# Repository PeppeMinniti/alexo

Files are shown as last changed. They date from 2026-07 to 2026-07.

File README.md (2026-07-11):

# Alexo — assistente vocale fai-da-te su ESP32-S3

Alexo è un assistente vocale "tipo Alexa/Google Home" **costruito da zero** su un
microcontrollore **ESP32-S3**: ascolta una domanda a voce e risponde a voce, con tanto
di chat sul display e animazioni luminose. Tutto il progetto (codice, commenti,
interfaccia) è in **italiano**.

<p align="center">
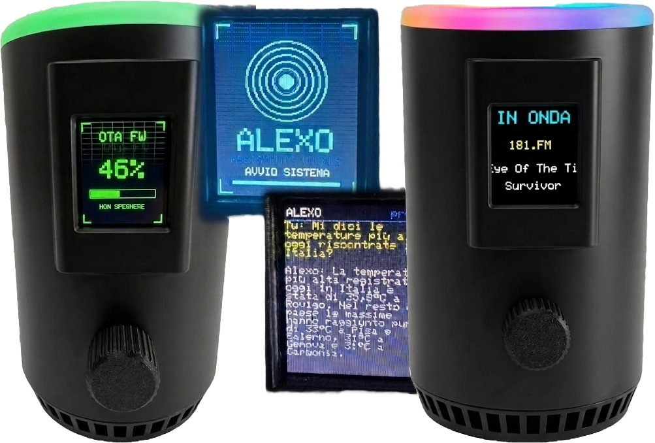
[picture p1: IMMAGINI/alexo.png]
Alexo — case stampato, splash di avvio, schermata OTA, chat sul display e schermata radio 'In onda'
  
</p>

> ⚠️ **Progetto hobbistico/educativo.** Per funzionare servono **3 API key tue**
> (vedi sotto). Nessuna garanzia: usalo a tuo rischio.

> 🖨️ **Il case è stampabile in 3D** — file `.3mf`/STL su
> **[MakerWorld](https://makerworld.com/it/models/3040023-alexo-ai-voice-assistant-case-esp32-s3)**
> (licenza CC BY 4.0).

---

## Come funziona

Alexo da solo è troppo piccolo per "ragionare": fa il **fattorino** tra alcuni servizi
cloud. L'unica intelligenza che gira in locale (offline) è il riconoscimento della parola
di attivazione.

```mermaid
flowchart TD
    START(["🗣️ Wake word 'Okay Nabu' (locale, offline)<br/>oppure click sull'encoder"])
    MIC["🎤 Microfono I2S<br/>registra la voce · stop automatico al silenzio"]
    STT["📤 Groq · Whisper<br/>voce → testo (STT, gratis)"]
    LLM["🧠 Claude · Anthropic<br/>il cervello · ricerca web"]
    TTS["🔊 ElevenLabs<br/>testo → voce (TTS, MP3)"]
    OUT["🔈 VS1053 → amplificatore → altoparlante"]
    UI["📺 Display TFT (chat) &nbsp;·&nbsp; 💍 Ring LED (stato)"]

    START --> MIC --> STT -->|testo| LLM -->|risposta| TTS --> OUT
    MIC -. aggiorna .-> UI
    LLM -. aggiorna .-> UI

    classDef cloud fill:#0e2a33,stroke:#00e5ff,color:#dfeef2;
    classDef ui fill:#1a1030,stroke:#ff2ea6,color:#dfeef2;
    class STT,LLM,TTS cloud;
    class UI ui;
```

Sul display TFT scorre la conversazione come un teleprompter; l'anello di LED cambia
animazione in base allo stato (ascolto / pensa / parla).

## Funzionalità

- 🗣️ **Wake word locale** "Okay Nabu" (microWakeWord / TensorFlow Lite Micro, offline)
- 🎛️ **Encoder** come comando unico (click per parlare, giro per scorrere/volume)
- 🧠 **Memoria della conversazione** + **ricerca web** (via Claude)
- ⏱️ **Stop automatico al silenzio** adattivo al rumore di fondo
- 📻 **Web-radio** MP3 ("metti radio…", cambio stazione dall'encoder)
- 🌐 **Pannello web** (`http://alexo.local/`): taratura parametri, volume, voci,
  personalità di Claude, e **chat in tempo reale** — senza ricompilare
- 🕒 **Ora reale** via NTP passata al cervello
- ⬆️ **Aggiornamento OTA** (via WiFi) oltre che via USB

## Hardware

| Componente | Modello | Ruolo |
| --- | --- | --- |
| MCU | ESP32-S3 **N16R8** (16 MB flash, 8 MB PSRAM) | il "computer" |
| Microfono | **ICS-43434** (I2S) | l'orecchio |
| Decoder audio | **VS1053 / VS1003** (SPI) | riproduce MP3 (voce e radio) |
| Amplificatore | **PAM8302A** | pilota l'altoparlante |
| Display | **ST7735** TFT 1.8" a colori | chat / teleprompter |
| Anello LED | **WS2812** 12 LED (NeoPixel) | animazioni di stato |
| Comando | Encoder rotativo **KY-040** | click / giro |

Schema dei collegamenti pin-per-pin e note di montaggio nel
[**MANUALE.md**](MANUALE.md) e in [CABLAGGIO_HW.md](CABLAGGIO_HW.md).

## Software

Firmware in **C++ / PlatformIO** (Arduino), modulare: `mic`, `net`, `stt`, `llm`, `tts`,
`music`, `ui` (LED), `gobbo` (display), `encoder`, `volume`, `sound`, `wakeword`,
`settings` + `webui` (pannello web). La pipeline pesante gira su un core, le animazioni
sull'altro, così restano fluide anche mentre Alexo "pensa".

## Come si costruisce (in breve)

1. **Clona** il repo e aprilo con [PlatformIO](https://platformio.org/) (in VS Code).
2. **Crea le tue chiavi API** (necessarie):
   - **Groq** (Whisper STT) — gratis su console.groq.com
   - **Anthropic** (Claude) — console.anthropic.com
   - **ElevenLabs** (voce TTS) — elevenlabs.io
3. **Configura i segreti**: copia `include/secrets.example.h` in `include/secrets.h` e
   inserisci WiFi + le 3 chiavi. (`secrets.h` è ignorato da git: non finirà nel repo.)
4. **Compila e carica** (primo flash via USB):
   
   ```
   pio run -e esp32-s3-devkitc-1 -t upload
   ```
   
   Serve caricare **una volta** anche la pagina del pannello web (cartella `data/`) nel
   filesystem dell'ESP — da ripetere solo se in futuro modifichi quella pagina:
     
   ```
   pio run -e esp32-s3-devkitc-1 -t uploadfs
   ```
 
5. Tutti i **pin e i parametri** stanno in [`include/config.h`](include/config.h) —
   unica fonte di verità.

La guida completa e spiegata passo-passo (con il *perché* di ogni scelta) è nel
[**MANUALE.md**](MANUALE.md). Dettagli sulla wake word in [WAKEWORD.md](WAKEWORD.md).

## Documentazione

- 📖 [MANUALE.md](MANUALE.md) — guida completa (hardware + software, spiegata semplice)
- 🔌 [CABLAGGIO_HW.md](CABLAGGIO_HW.md) — collegamenti pin-per-pin
- 🧩 [WAKEWORD.md](WAKEWORD.md) — la wake word locale nel dettaglio
- 🖨️ [Case 3D su MakerWorld](https://makerworld.com/it/models/3040023-alexo-ai-voice-assistant-case-esp32-s3) — file stampabili (`.3mf`/STL), licenza CC BY 4.0

---

## 👤 Autore

**Peppe Minniti** — *Automation Engineer* dal profilo atipico: nessun titolo in
ingegneria, tanta pratica. Costruisco sistemi che integrano hardware, software e
meccanica. Alexo è uno dei miei progetti. Il mio motto: **"Soluzioni che funzionano".**

### 🆘 Sei bloccato su un tuo ESP32?

**Lo risolviamo insieme, in diretta.** Diagnosi gratuita, poi sessione 1:1 in
condivisione schermo. → **[Vai a ESP32 SOS ›](https://www.peppeminniti.it/assistenza_esp32/)**

<sub>Oppure impara a costruirli tu: [corso completo "Dall'idea al sistema con ESP32"](https://www.peppeminniti.it/) · [Portfolio](https://www.peppeminniti.it/portfolio/) · [GitHub](https://github.com/PeppeMinniti) · [LinkedIn](https://www.linkedin.com/in/giuseppe-minniti-m2m-fablab)</sub>

## Licenza

Rilasciato sotto licenza **MIT** — vedi [LICENSE](LICENSE). Puoi usarlo, modificarlo e
ridistribuirlo liberamente, mantenendo la nota di copyright.

## Ringraziamenti

Ideazione, progettazione, scelte tecniche, prove sul campo e cura del risultato finale
sono di **Giuseppe Minniti**. Parte dello sviluppo è stata portata avanti in
collaborazione con un assistente AI (Claude, di Anthropic), usato come compagno di
lavoro: per confrontare idee, scrivere e commentare codice, rifinire la documentazione.

Mi piace pensarla come una collaborazione in cui si cresce a vicenda: l'AI non
sostituisce il lavoro e le decisioni umane, le affianca e le accelera. La direzione, il
senso critico e la responsabilità delle scelte restano di chi progetta — e proprio da
questo dialogo nasce l'occasione di imparare, per entrambe le parti.

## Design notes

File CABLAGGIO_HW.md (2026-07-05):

# ALEXO — Guida al cablaggio hardware

Riepilogo completo di **tutti** i collegamenti pin-a-pin tra i componenti, con
condensatori, resistenze, varianti di nomenclatura serigrafata sui moduli e
buone norme. Niente schemi ASCII: solo elenchi "da pin a pin".

Fonte dei pin: [`include/config.h`](include/config.h) — **unica fonte di verità**.
Se cambi un cablaggio, modifica i `#define` lì, non altrove.

---

## Premesse generali (valgono per tutto)

- **L'ESP32-S3 lavora a 3.3V sui pin.** Mai mettere 5V su un GPIO. I moduli si
  alimentano dal pin `5V` (chiamato anche `VIN` / `VBUS`) o dal `3V3` della
  board a seconda del componente — specificato sotto per ognuno.
- **GND comune obbligatorio.** Tutti i GND di tutti i moduli (mic, VS1053,
  display, ring, encoder, bottone) devono finire sullo stesso GND della ESP32.
  Senza massa comune i segnali "ballano" e niente funziona. È la regola d'oro:
  se un modulo si comporta in modo strano, il primo sospetto è sempre una massa
  mancante o ballerina.
- **Pin da NON toccare** su questa board (ESP32-S3 N16R8): GPIO 33–37 (PSRAM
  octal), 19/20 (USB), 0/3/45/46 (strapping). Sono già evitati nella config.

---

## Microfono — DUE opzioni (se ne collega UNA sola)

La scelta si fa con `MIC_USE_I2S` in [`config.h`](include/config.h):
`1` = mic I2S digitale ICS-43434 (**in uso ora**), `0` = MAX4466 analogico
(backend alternativo). L'API software è identica → cambi solo la riga, ricompili,
ricabli.

### Opzione A — MAX4466 analogico (alternativo, `MIC_USE_I2S 0`)

| Pin sul modulo MAX4466 | Va collegato a | Note |
|---|---|---|
| `VCC` (`VDD` / `V` / `+`) | **3V3** della ESP32 | **Non** 5V: a 5V il livello DC di riposo esce dal range dell'ADC |
| `GND` (`G` / `-`) | GND comune | — |
| `OUT` (`AUD` / `A0` / `S`) | **GPIO4** (ADC1_CH3) | uscita analogica |

**Condensatore (importante, già previsto nel progetto):** **470 µF elettrolitico
tra VCC e GND del MAX4466**, il più vicino possibile al modulo. Disaccoppia
l'alimentazione: senza, i NeoPixel che si accendono "sporcano" la tensione e il
mic capta i loro disturbi (l'idle reattivo non funziona). Polarità: gamba lunga
(+) su VCC, gamba corta / lato con striscia chiara e segno `–` su GND.

Il guadagno si regola col **trimmer sul retro** del MAX4466 (cacciavite piccolo),
nessuna resistenza esterna.

### Opzione B — mic I2S digitale ICS-43434 / INMP441 (IN USO ORA, `MIC_USE_I2S 1`)

Microfono digitale: niente ADC, niente condensatori di disaccoppiamento (sparisce
del tutto l'accoppiamento LED→mic). Alimentare a **3V3**.

| Pin sul modulo I2S | Va collegato a | Nomi possibili sul modulo |
|---|---|---|
| Alimentazione | **3V3** | `VDD`, `VCC`, `3V3`, `+` |
| Massa | GND comune | `GND`, `G`, `-` |
| Bit clock | **GPIO5** | `SCK`, `BCLK`, `CLK`, `SCLK` |
| Word select | **GPIO6** | `WS`, `LRCL`, `LRCLK`, `FS` |
| Dati dal microfono | **GPIO7** | `SD`, `DOUT`, `DATA`, `DO` |
| Selezione canale | **GND** | `L/R`, `SEL`, `LRSEL` → a **GND = canale LEFT** (quello che il codice si aspetta) |

> Sul modulo INMP441 può esserci anche `VDD`/`GND` doppi: collega comunque tutti
> i GND. Il pin `L/R` a GND seleziona LEFT; a 3V3 selezionerebbe RIGHT (da evitare).

**Buone norme I2S:**
- Niente resistenze/condensatori esterni necessari.
- Dopo lo swap va **ri-tarata** la soglia dell'idle reattivo
  (`MIC_LVL_NOISE` / `MIC_LVL_GAIN` nel ramo I2S di [`src/mic.cpp`](src/mic.cpp))
  e l'`I2S_SHIFT` in config (alza = più volume, conversione 32→16 bit).
- I tre fili dati (SCK/WS/SD) tienili cortini e lontani dai fili audio/SPI.

---

## VS1053 (decoder MP3 → altoparlante, bus SPI)

È il modulo con più nomi diversi sulla serigrafia. Per ogni funzione elenco
**tutte** le diciture possibili (LC Technology, Adafruit, Sparkfun, cloni):

| Funzione / pin nel codice | GPIO ESP32 | Nomi possibili sul modulo |
|---|---|---|
| **Alimentazione** | `5V` | `5V`, `VCC`, `V+`, `VIN` — i moduli LC Technology vogliono **5V** (regolatore a bordo) |
| **Massa** | GND | `GND`, `G`, `-` |
| **Clock SPI (SCK)** | `GPIO12` | `SCK`, `SCLK`, `CLK`, `C` |
| **Dati verso il VS1053 (MOSI)** | `GPIO11` | `MOSI`, `SI`, `DI`, `SDI`, `DIN` |
| **Dati dal VS1053 (MISO)** | `GPIO13` | `MISO`, `SO`, `DO`, `SDO`, `DOUT` |
| **Chip Select comandi (XCS)** | `GPIO10` | `XCS`, `CS`, `SCS`, `xCS` |
| **Chip Select dati (XDCS)** | `GPIO21` | `XDCS`, `DCS`, `BSYNC`, `SDCS`, `X-DCS` |
| **Data Request (DREQ)** | `GPIO18` | `DREQ`, `DREQ/INT`, `DQ`, `D-REQ` — **uscita** del VS1053 (input per la ESP32): "sono pronto a ricevere altri dati". Spostato da GPIO47 a **GPIO18** |
| **Reset (XRST)** | `GPIO8` | `XRST`, `RST`, `RESET`, `XRESET`, `RES` — spostato da GPIO38 (era il "BUILTIN LED" della board: sporcava XRST durante il float di boot → reset del VS1003 inaffidabile a freddo) |

Altri pin presenti sul connettore VS1053 e cosa farne:
- **`AGND` / `LOUT` / `ROUT` / `GBUF`**: uscita audio analogica / cuffie.
  `LOUT`/`ROUT` = canale sinistro/destro, `GBUF` = massa virtuale cuffie.
  Vanno all'altoparlante (via ampli o jack), **non** alla ESP32.
- **Slot microSD** (`CARD_CS` o un secondo gruppo `CS/SCK/MISO/MOSI`): molti
  moduli LC Technology ce l'hanno sullo stesso bus SPI. Se non lo usi, lascialo
  scollegato (CS della SD non collegato = SD disabilitata).
- **`MIDI` / `RX` / `GPIO0..3` del VS1053**: pin di modalità/MIDI, non servono.

**Buone norme VS1053:**
- È sullo **stesso bus SPI (FSPI)** della board (SCK/MOSI/MISO condivisi); il
  display sta su un **bus separato (HSPI)** apposta per non litigare. Non
  spostare il VS1053 sul bus del display.
- Se "si pianta" sui suoni brevi (bip) è un comportamento noto del chip già
  gestito nel codice (niente `stopSong`, si manda una coda di silenzio). Non è
  un problema di cablaggio.

> ⚠️ Conflitto da ricordare: `GPIO13` è MISO del VS1053 **e** sarebbe `I2S_SHIFT`
> nel ramo I2S — ma sono mutuamente esclusivi (il `13` lì è solo un parametro
> numerico di shift, non un pin). Nessun conflitto reale.

---

## Amplificatore PAM8302A (ampli Class-D mono → altoparlante)

Amplifica l'uscita di linea del VS1053 per pilotare un altoparlante a volume
pieno. L'**ingresso** del PAM si prende dall'uscita audio del VS1053, **non** da
un GPIO.

| Funzione / pin nel codice | Va collegato a | Nomi possibili sul modulo |
|---|---|---|
| **Alimentazione** | `5V` | `VDD`, `VCC`, `V+`, `5V` (regge 2.0–5.5V) |
| **Massa** | GND comune | `GND`, `G`, `-` |
| **Ingresso audio +** | **`LOUT`** (o `ROUT`) del VS1053 | `IN+`, `A+`, `IN`, `L` |
| **Ingresso audio −** | **`AGND`** del VS1053 | `IN-`, `A-`, `GND audio` |
| **Shutdown** | **`GPIO39`** | `SD`, `/SD`, `SHDN`, `EN` |
| **Uscita +/−** | altoparlante | `+`/`-`, `OUT+`/`OUT-` |

**Pin SD (shutdown), ATTIVO BASSO — gestito dal firmware:**
- `HIGH` = ampli acceso; `LOW` = ampli **muto** (consumo ~0, **niente fruscio**
  Class-D di fondo, niente pop). Sulla maggior parte delle breakout, se lasci SD
  **scollegato** l'ampli resta acceso (pull-up a bordo).
- Il firmware lo tiene acceso **solo durante l'interazione** (bip + voce) e muto
  a riposo: vedi `AMP_SD_PIN` in [`config.h`](include/config.h) e `ampEnable()`
  in [`src/main.cpp`](src/main.cpp). Metti `AMP_SD_PIN -1` per disabilitare il
  controllo (ampli sempre acceso).
- **Per provarlo "fisso acceso"**: porta SD alla **stessa tensione di VDD**
  (se alimenti il PAM a 5V → SD a 5V). Mai SD sopra la VDD dell'ampli.

> Nota pin: `GPIO39` fa parte del gruppo JTAG (MTCK), già rinunciato dal progetto
> (40/41/42 = MTDO/MTDI/MTMS sono il display). Nessun conflitto.

---

## Encoder rotativo KY-040 (scroll della chat sul display)

| Funzione / pin nel codice | GPIO ESP32 | Nomi possibili sul modulo |
|---|---|---|
| **Alimentazione** | **3V3** | `+`, `VCC`, `V`, `5V` (sul KY-040 c'è scritto `+`; **alimentalo a 3V3**, non 5V) |
| **Massa** | GND | `GND`, `G`, `-` |
| **Canale A (CLK)** | `GPIO15` | `CLK`, `A`, `OUT_A`, `S1`, `ENC_A` |
| **Canale B (DT)** | `GPIO16` | `DT`, `B`, `OUT_B`, `S2`, `ENC_B` |
| **Pulsante (premere la manopola)** | `GPIO17` | `SW`, `KEY`, `BTN`, `PUSH`, `S` |

> ⚠️ **Cablaggio fisico vs firmware (situazione attuale, funzionante):** sopra c'è
> il cablaggio FISICO reale (CLK→GPIO15, DT→GPIO16). In [`config.h`](include/config.h)
> però i `#define` sono **invertiti apposta** — `ENC_A_PIN 16`, `ENC_B_PIN 15` —
> per correggere via software il verso di rotazione (A/B erano risultati scambiati
> in saldatura). **Non "raddrizzare" i define per farli combaciare con questa
> tabella**: girando i due valori si inverte il senso dello scroll. Così com'è,
> gira e scrolla nel verso giusto.

Funzione: girare = scorri la chat su/giù; premere il pulsante = torna "live".

**Resistenze / condensatori sull'encoder:**
- Il **KY-040** ha già a bordo due resistenze di pull-up (10kΩ) su CLK e DT. Con
  un encoder "nudo" servirebbero pull-up esterne — ma in pratica si usano le
  **pull-up interne della ESP32** via software (`INPUT_PULLUP`): non saldi nulla.
- Gli encoder meccanici "rimbalzano". Opzionale: **100 nF ceramico tra CLK e GND
  e un altro tra DT e GND** pulisce molto la lettura. I ceramici **non** hanno
  polarità, vanno in qualunque verso.

---

## Bottone push-to-talk — RIMOSSO (l'encoder è l'unico comando)

Non c'è un bottone dedicato: il contenitore ha il **solo encoder**. Il pulsante
dell'encoder fa tutto. **GPIO14**, ex push-to-talk, è ora riusato per il
**backlight del display** (vedi sezione TFT ST7735).

Gesti dell'encoder (vedi [`src/gobbo.cpp`](src/gobbo.cpp)):

| Gesto | Effetto |
|---|---|
| **Click** (a riposo) | avvia la chat (inizia a registrare) |
| **Click** (mentre registra) | ferma e invia *(toggle)* |
| **Premuto + giro** | volume su/giù |
| **Giro libero** | scroll della chat |

> Predisposizione per il futuro vocale: il "click di avvio" sarà rimpiazzato dal
> **wake-word** e il "click di stop" dal **rilevamento del silenzio**, senza
> toccare il resto della pipeline (start/stop sono già eventi separati).

---

## Ring NeoPixel WS2812 (12 LED)

| Pin sul ring | Va collegato a | Note |
|---|---|---|
| `5V` (`VCC` / `+5V` / `PWR` / `+`) | **5V** | i WS2812 vogliono 5V per colori pieni |
| `GND` (`-` / `G`) | GND comune | — |
| `DIN` (`DI` / `IN` / `Data In`, segui la freccia ➜ stampata) | **GPIO48** | il dato entra dal lato `DIN`, non `DOUT` |

**Condensatori e resistenze (raccomandati, in parte già nel progetto):**
- **1000 µF elettrolitico tra 5V e GND del ring**, vicino al ring. Già previsto:
  assorbe i picchi di corrente quando i LED cambiano colore insieme (altrimenti
  disturbano il mic). Polarità: + su 5V, – (striscia chiara) su GND.
- **Resistenza ~330 Ω in serie sul filo DIN** (tra GPIO48 e l'ingresso dati del
  ring). Protegge il primo LED e fa da rimedio anti-EMI. Senza polarità; va *in
  linea* sul filo dati (taglia il filo e metti la resistenza in mezzo).

**Nota EMI (già documentata):** tieni il filo `DIN` del ring **lontano** dai fili
SCLK/MOSI del display, altrimenti l'accoppiamento elettromagnetico fa lampeggiare
il ring durante lo scroll. La resistenza serie da 330 Ω sul DIN aiuta anche qui.

---

## Display TFT ST7735 1.8" (bus SPI dedicato HSPI)

| Funzione / pin nel codice | GPIO ESP32 | Nomi possibili sul modulo |
|---|---|---|
| Clock | `GPIO2` | `SCK`, `SCL`, `CLK` |
| Dati | `GPIO1` | `SDA`, `MOSI`, `DIN`, `SI` |
| Chip Select | `GPIO42` | `CS`, `LCD_CS` |
| Data/Command | `GPIO41` | `DC`, `A0`, `RS`, `D/C` |
| Reset | `GPIO40` | `RES`, `RST`, `RESET` |
| Alimentazione | `3V3` | `VCC`, `VDD` |
| Massa | GND | `GND` |
| Retroilluminazione | `GPIO14` | `LED`, `BL`, `BLK` |

**Retroilluminazione su GPIO (novità):** il pin `LED`/`BL` **non** va più a 3V3
fisso ma a **GPIO14** (era libero, ex push-to-talk). Così il firmware può
**spegnere il display a riposo** (dopo `DISPLAY_SLEEP_MS`, default 2 min) e
riaccenderlo al primo intervento. Il pin assorbe **~2 mA** (misurati): si pilota
**direttamente dal GPIO**, *niente transistor né resistenza esterna* (il catodo
del LED è già a GND dentro il modulo, e la resistenza di limitazione è a bordo).
HIGH = acceso, LOW = spento. Se volessi tenerlo sempre acceso: `DISPLAY_SLEEP_MS 0`
in [`config.h`](include/config.h).

Nessun passivo extra oltre a quelli a bordo del modulo. Se vedi "garbage" a
schermo è questione di clock SPI (scendi da 24 MHz a 16/20 MHz in config), non di
cablaggio.

---

## Riepilogo componenti passivi da avere

| Componente | Quantità | Dove | Polarità? |
|---|---|---|---|
| Elettrolitico **470 µF** | 1 | VCC↔GND del MAX4466 (solo mic analogico) | **Sì** (+ su VCC) |
| Elettrolitico **1000 µF** | 1 | 5V↔GND del ring | **Sì** (+ su 5V) |
| Resistenza **330 Ω** | 1 | in serie sul filo DIN del ring | No |
| Ceramico **100 nF** | 0–2 (opz.) | CLK↔GND e DT↔GND dell'encoder | No |

> Con il **mic I2S** il 470 µF del mic **non serve più** (mic digitale).

**Polarità di un elettrolitico, in due parole:** gamba **lunga = +**; sul corpo
c'è una **striscia chiara col segno `–`** dal lato della gamba corta. Il `+` va
verso l'alimentazione (VCC o 5V), il `–` verso GND. Resistenze e ceramici si
montano in qualunque verso.

---

## Tabella riassuntiva GPIO usati

> 📌 Pinout di riferimento in [`IMMAGINI/`](IMMAGINI/): `esp32-S3-DevKitC-1.png`
> (vista dall'alto, lato componenti) e `esp32-S3-DevKitC-1_LATO-SALDATURE.png`
> (vista da **sotto**, lato saldature — lati invertiti ma testo leggibile, utile
> mentre saldi guardando il retro della board).

| GPIO | Componente | Segnale |
|---|---|---|
| 1 | TFT ST7735 | MOSI/SDA |
| 2 | TFT ST7735 | SCLK/SCL |
| 4 | MAX4466 | OUT (ADC1) — *solo mic analogico* |
| 5 | mic I2S | BCLK — *solo mic I2S* |
| 6 | mic I2S | WS — *solo mic I2S* |
| 7 | mic I2S | SD (dati) — *solo mic I2S* |
| 10 | VS1053 | XCS |
| 11 | VS1053 | MOSI |
| 12 | VS1053 | SCK |
| 13 | VS1053 | MISO |
| 14 | TFT ST7735 | LED/BL (backlight, ex push-to-talk) |
| 15 | Encoder | A / CLK |
| 16 | Encoder | B / DT |
| 17 | Encoder | SW (pulsante = avvia/ferma chat) |
| 21 | VS1053 | XDCS |
| 8 | VS1053 | XRST (spostato da GPIO38 = builtin LED) |
| 39 | PAM8302A | SD (shutdown ampli) |
| 40 | TFT ST7735 | RST |
| 41 | TFT ST7735 | DC/A0/RS (Data/Command) |
| 42 | TFT ST7735 | CS |
| 18 | VS1053 | DREQ (spostato da GPIO47) |
| 48 | Ring WS2812 | DIN |

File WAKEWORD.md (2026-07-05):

# ALEXO — Wake word locale (microWakeWord)

Wake word **offline** sull'ESP32-S3 per avviare la chat a voce, in parallelo al
click encoder. Tutto in locale (nessun cloud per il wake).

> Stato: ✅ **FUNZIONANTE** — wake word **"Okay Nabu"** integrato e testato.
> Tutti i passi sotto sono FATTI. Implementazione in
> `src/wakeword.cpp` (+ `src/wake_model.h`, `lib/microfrontend/`), attiva con
> `WAKE_ENABLE 1` in `config.h`.
>
> **Parola attuale = "Okay Nabu"** (modello pre-addestrato): si pronuncia
> bene ed è preciso. Scartati "hey jarvis" (non colto per l'accento) e "alexa"
> (scattava su qualsiasi "-xa"). **"Alexo" CUSTOM** = unico upgrade rimasto (serve
> allenare un modello microWakeWord via Colab; nessuna registrazione, voci
> sintetiche; ~30-60 min con guida). Drop-in: sostituire `wake_model.h` + i `WAKE_*`.
>
> **Tuning finale**: WAKE_GAIN=4, WAKE_PROB_CUTOFF=240, WAKE_WINDOW=5. Lezioni:
> il modello è STREAMING → vuole flusso CONTINUO (niente delay tra le letture, o
> non rileva); troppo guadagno SATURA e peggiora; dopo l'interazione servono
> `micFlush()`+`wakeReset()` o riparte da solo sull'audio stantio.

## Architettura target

```
🎤 I2S 16kHz (continuo) → [feature frontend: 40 mel ogni 10ms]
   → modello microWakeWord INT8 (MixNet streaming, inferenza ogni 20ms, <10ms su S3)
   → probabilità wake → soglia + debounce (N inferenze consecutive sopra soglia)
   → TRIGGER: stesso ingresso del click encoder (gobboTakeTalkRequest)
              → pipeline cloud già pronta (Groq → Claude → ElevenLabs)
```

Il wake **sostituisce solo l'avvio**; tutto il resto della pipeline è invariato.
Il click encoder resta come avvio manuale e come stop.

## Dati tecnici (verificati giu 2026)

- Modello: **INT8 TFLite ~200–240 KB**, architettura MixNet streaming (stato interno).
- Frontend: **40 feature spettrali ogni 10 ms** (tipo mel/micro_speech, con
  noise-suppression + AGC nel preprocessore).
- Inferenza ogni **20 ms** sull'ultima stride; **<10 ms** su ESP32-S3 (con esp-nn).
- RAM: **~350 KB** (tensor arena) → allocare in **PSRAM** (`ps_malloc`), ne abbiamo 8 MB.
- Flash: il modello (~240 KB) come array `const` in `.rodata` (16 MB di flash, ampio).

## Toolchain TFLite Micro — LA decisione critica (da validare con un build)

Il progetto è Arduino/PlatformIO; TFLite Micro nasce ESP-IDF. Due strade:

1. **`esp-tflite-micro`** (Espressif): massima performance (kernel ottimizzati
   `esp-nn` sulle istruzioni vettoriali dell'S3). È un componente ESP-IDF: in
   PlatformIO-Arduino va aggiunto come componente, integrazione più delicata.
2. **Libreria Arduino che impacchetta TFLM + microfrontend** (es. EdgeNeuron, o un
   port `tflite-micro` per Arduino): più facile da mettere in `lib_deps`, ma può
   non avere l'accelerazione esp-nn e usare una versione TF più vecchia.

> **Azione**: provare a buildare un'inferenza MINIMALE con (1) e, se troppo
> ostico in Arduino, ripiegare su (2). Questo è il primo vero esperimento: finché
> non compila e gira una `Invoke()` su un tensore fittizio, il resto è teoria.

## Passi (in ordine, ciascuno verificabile via OTA)

1. **[FATTO] Step 0 — mic pulito.** Passa-alto + shift 15 + diagnostica `MIC_DIAG`.
2. **TFLite Micro compila e gira.** Aggiungere la lib scelta, far girare una
   `Invoke()` banale on-device (anche su input finto). Verifica: nessun crash,
   tempi di inferenza stampati su Telnet (`netlog`). ← de-risk della toolchain.
3. **Frontend feature.** Generare le 40 feature/10 ms dallo stream I2S (libreria
   microfrontend di TFLM). Verifica: dump dei valori su Telnet con voce vs silenzio.
4. **Modello PRE-ADDESTRATO.** Scaricare un modello pronto da
   `esphome/micro-wake-word-models` (es. "hey jarvis"), incorporarlo come array,
   collegarlo frontend→modello, stampare la probabilità su Telnet. Verifica:
   pronunciando la parola la probabilità sale. ← prova che la catena funziona.
5. **Soglia + debounce + trigger.** Sopra soglia per N inferenze consecutive →
   chiama l'avvio chat (stesso punto del click encoder). Tuning anti-falsi-positivi.
6. **Modello "Alexo" CUSTOM.** Allenarlo col Colab di `OHF-Voice/micro-wake-word`
   (campioni sintetici via TTS), esportare INT8, sostituire l'array del passo 4.
7. **Rifinitura**: gestione stato "sordo durante la chat", rientro in ascolto,
   eventuale doppia conferma, consumo.

## Stato implementazione (aggiornato giu 2026)

- **Passo 2 FATTO ✅**: TFLite Micro gira sull'S3. Lib = **Chirale_TensorFlowLite**
  (in `platformio.ini`). Self-test `hello_world` (`TFL_SELFTEST` + `src/tfltest.cpp`
  + `src/tfl_hello_model.h`): inferenza 38–132 µs, output corretti. `esp-tflite-micro`
  scartato (gira male in PlatformIO).
- **Modello scelto**: microWakeWord **v2 "alexa"** (vicino ad "Alexo"), da
  `esphome/micro-wake-word-models/models/v2/alexa.tflite`. Già incorporato in
  **`src/wake_model.h`** (`g_wake_model`, 55856 byte, INT8). Manifest v2:
  `probability_cutoff=0.9`, `sliding_window_size=5`, `feature_step_size=10ms`,
  `tensor_arena_size=22348` (~22 KB, in PSRAM). Detection: media mobile della
  probabilità su 5 step > 0.9 (+ refrattario anti-ripetizione).

### Frontend feature — specifica ESATTA (deve combaciare col training)
Preprocessore micro_speech / **TFLM microfrontend** (`tensorflow/lite/experimental/
microfrontend/lib/`), config da `preprocessor_settings.h` di ESPHome:
- sample rate **16000**, finestra **30 ms** (480 camp.), passo **10 ms** (160 camp.)
- **40** canali mel, banda **125–7500 Hz**
- noise reduction: smoothing_bits=10, even=0.025, odd=0.06, min_signal_remaining=0.05
- PCAN: enable=true, strength=0.95, offset=80.0, gain_bits=21
- log scale: enable=true, scale_shift=6
- output: 40 feature INT8/UINT8 per slice (un'inferenza ogni step da 10 ms).

### Vendorizzazione microfrontend (passo 3, IN CORSO)
Chirale NON include il microfrontend → va vendorizzato in `lib/microfrontend/`.
File core da `tensorflow/lite/experimental/microfrontend/lib/` (no _io/_test/_main/
memmap/BUILD): frontend, frontend_util, filterbank(+util), noise_reduction(+util),
pcan_gain_control(+util), log_scale(+util), log_lut, window(+util), fft, fft_util,
kiss_fft_int16, kiss_fft_common.h, bits.h. **Dipendenza kissfft**: kiss_fft_int16
include, dentro `namespace kissfft_fixed16` con `FIXED_POINT=16`, i sorgenti kissfft
`kiss_fft.h/.c`, `tools/kiss_fftr.h/.c` (+ `_kiss_fft_guts.h`) dal repo
mborgerding/kissfft alla versione di `tensorflow/lite/micro/tools/make/kissfft_download.sh`
(+ `third_party/kissfft/kissfft.patch`). Struttura lib PlatformIO:
`lib/microfrontend/src/tensorflow/...` (per gli include assoluti TFLM) e i sorgenti
kissfft raggiungibili come `kiss_fft.h`/`tools/kiss_fftr.h` dall'include path.

## Integrazione audio (nota importante)

Oggi a riposo il `loop()` fa `micPeekLevel()` (un `i2s_read` per il ring reattivo).
Col wake servirà leggere **tutto** lo stream in continuo: si unificherà la lettura
I2S a riposo in modo che lo **stesso** chunk alimenti sia il livello del ring sia
il buffer del wake (niente doppio `i2s_read`, altrimenti il modello perde metà
audio). Vedi seam in `wakeword.cpp` / `main.cpp` (`WAKE_ENABLE`).

## Cosa serve da te (in parallelo)

- Per il passo 6: far girare il **Colab di microWakeWord** per allenare "Alexo"
  (genera campioni sintetici, ~decine di minuti). Output: un `.tflite` INT8 + i
  parametri del frontend. Te lo guido quando arriviamo lì.
- Per i passi 2–5 non serve nulla da te se non flashare e leggere il Telnet.

## Fonti
- microWakeWord: https://microwakeword.com/ (train: https://microwakeword.com/train)
- Repo training: https://github.com/OHF-Voice/micro-wake-word
- Modelli pronti: https://github.com/esphome/micro-wake-word-models
- esp-tflite-micro: https://github.com/espressif/esp-tflite-micro
- ESPHome micro_wake_word: https://esphome.io/components/micro_wake_word/
- Guida pratica S3+TFLM: https://dev.to/zediot/esp32-s3-tensorflow-lite-micro-a-practical-guide-to-local-wake-word-edge-ai-inference-5540

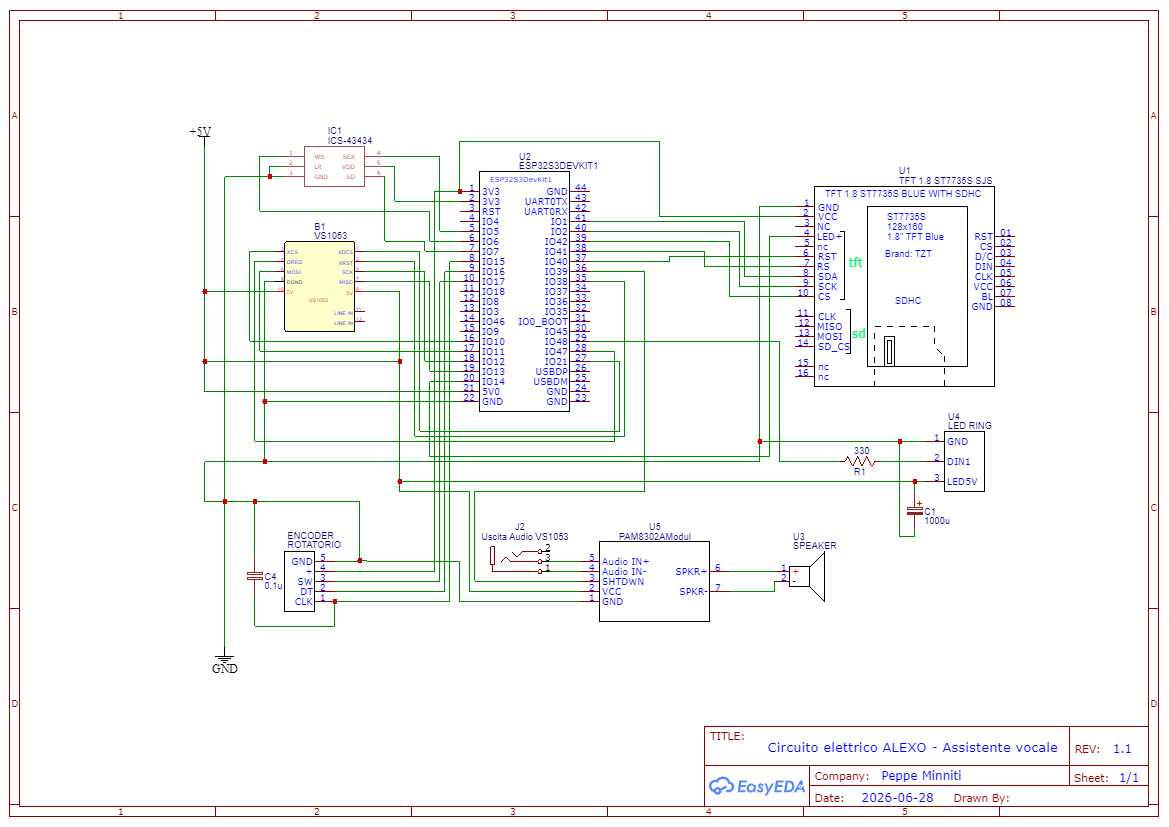
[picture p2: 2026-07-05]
IMMAGINI/Schematic_alexo_2026-07-04.png

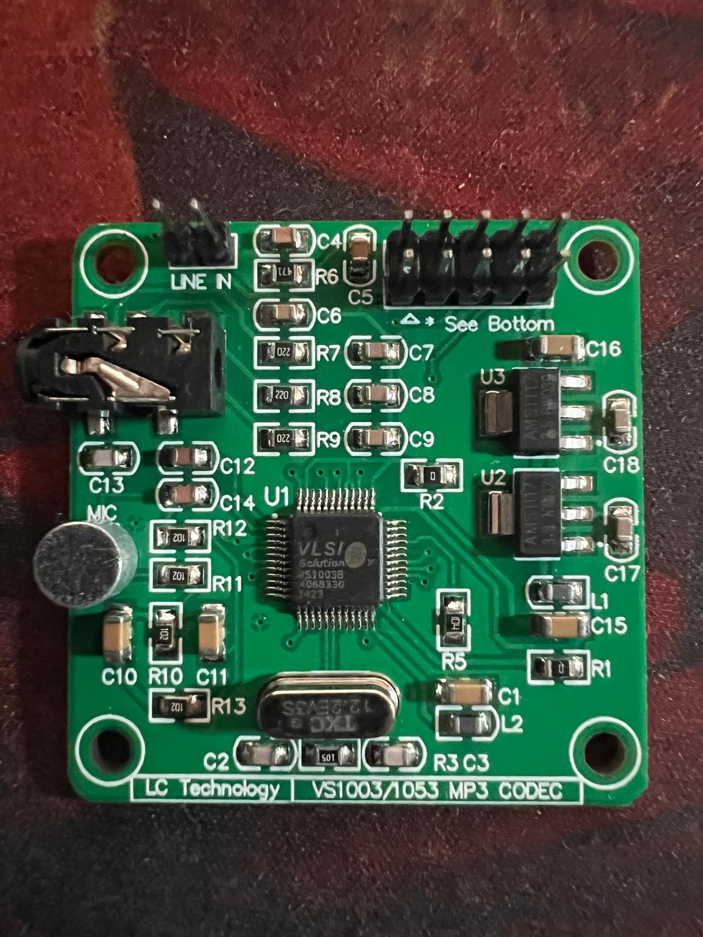
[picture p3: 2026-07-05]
IMMAGINI/codec_mp3.jpeg

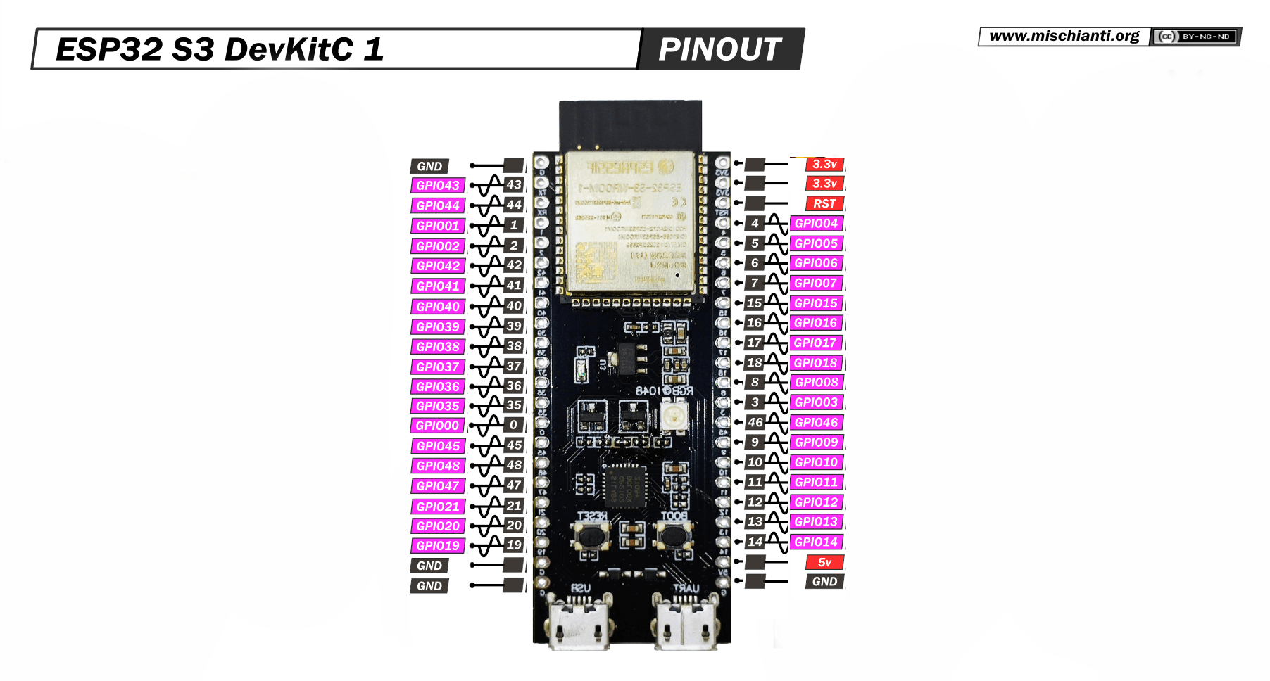
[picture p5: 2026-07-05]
IMMAGINI/esp32-S3-DevKitC-1_LATO-SALDATURE.png

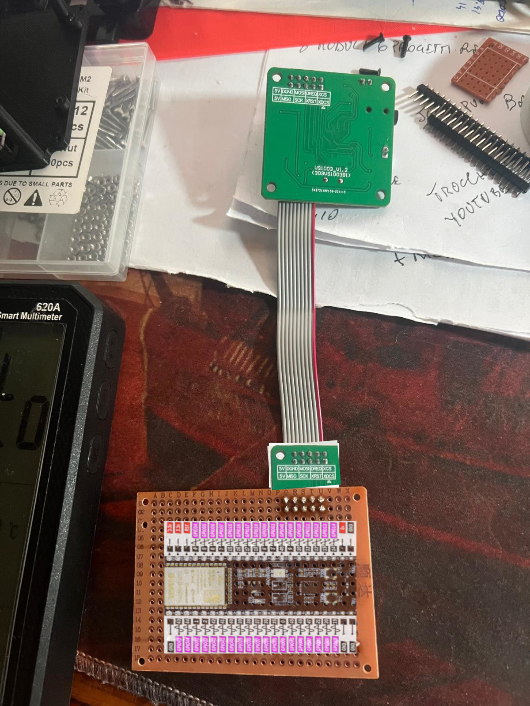
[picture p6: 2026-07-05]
IMMAGINI/basette.jpeg

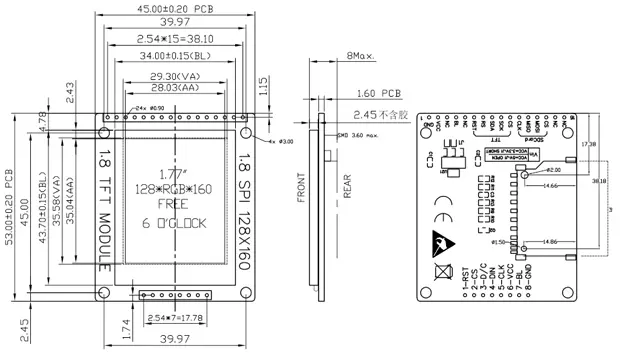
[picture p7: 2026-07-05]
IMMAGINI/Drawing1.8-inch-TFT-1.webp

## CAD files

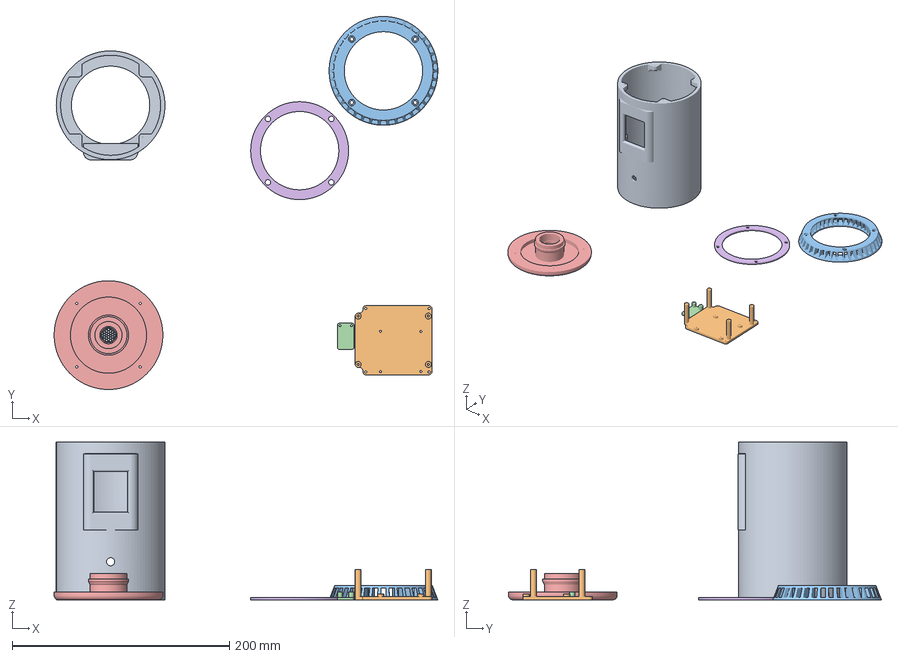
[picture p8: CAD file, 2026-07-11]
3d/Alexo.3mf
352.8 x 343.0 x 145.0 mm
contenitore.stl
basetta vs1053-1.stl
base.stl
basetta ampli.stl
coperchio portaled.stl
guarnizione.stl

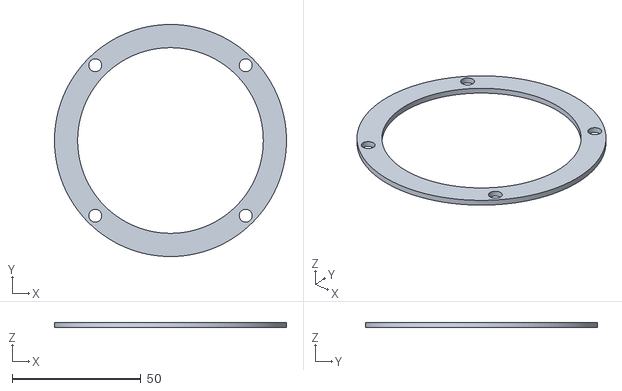
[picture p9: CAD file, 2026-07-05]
3d/guarnizione.stl
90.0 x 90.0 x 2.00

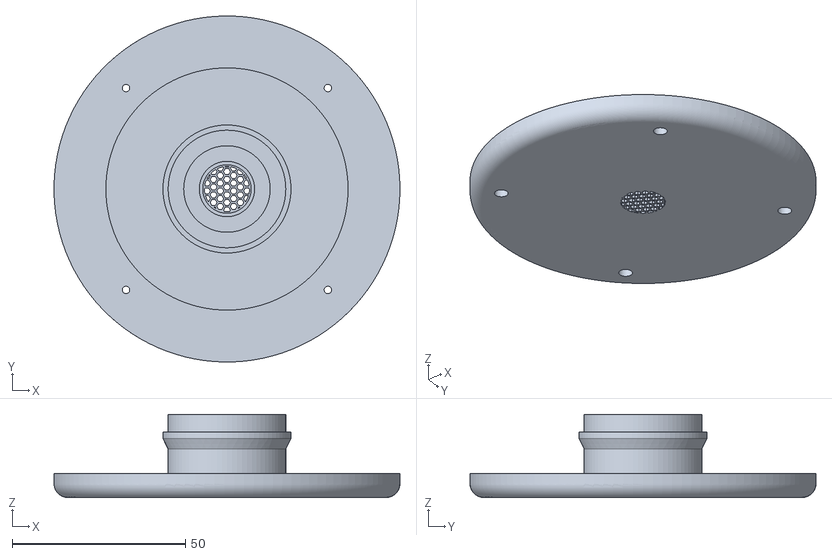
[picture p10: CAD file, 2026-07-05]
3d/coperchio portaled.stl
100.0 x 100.0 x 24.0

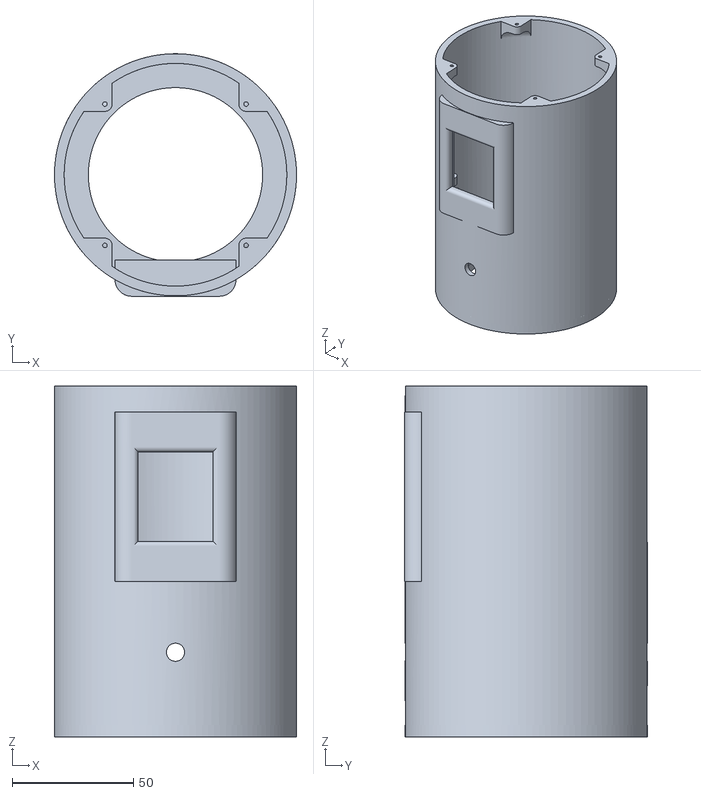
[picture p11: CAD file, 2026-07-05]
3d/contenitore.stl
100.0 x 100.2 x 145.0

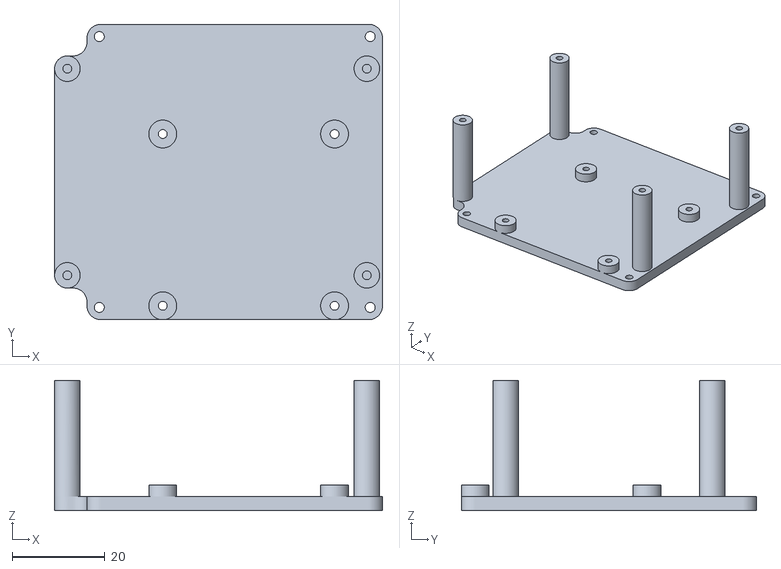
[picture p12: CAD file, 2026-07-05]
3d/basetta vs1053.stl
70.6 x 63.6 x 28.0

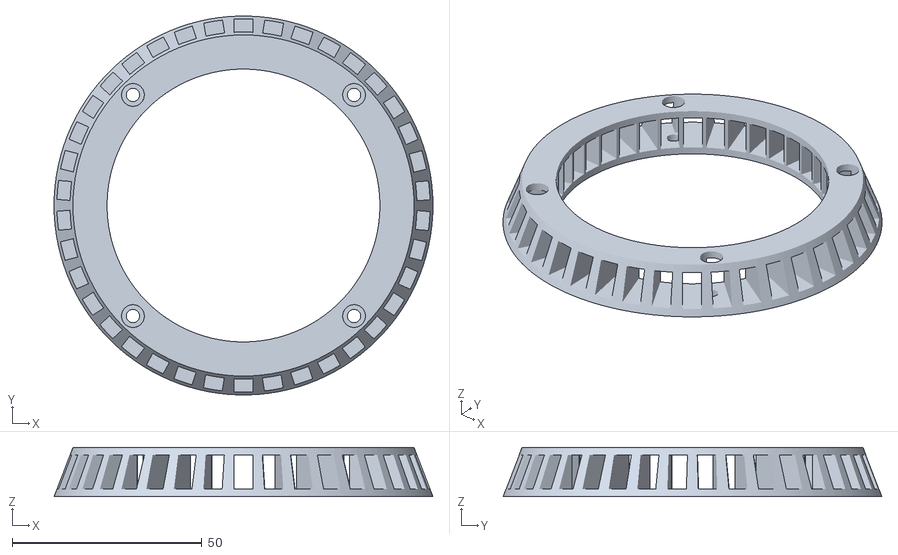
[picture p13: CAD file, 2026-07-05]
3d/base.stl
100.0 x 100.0 x 13.0

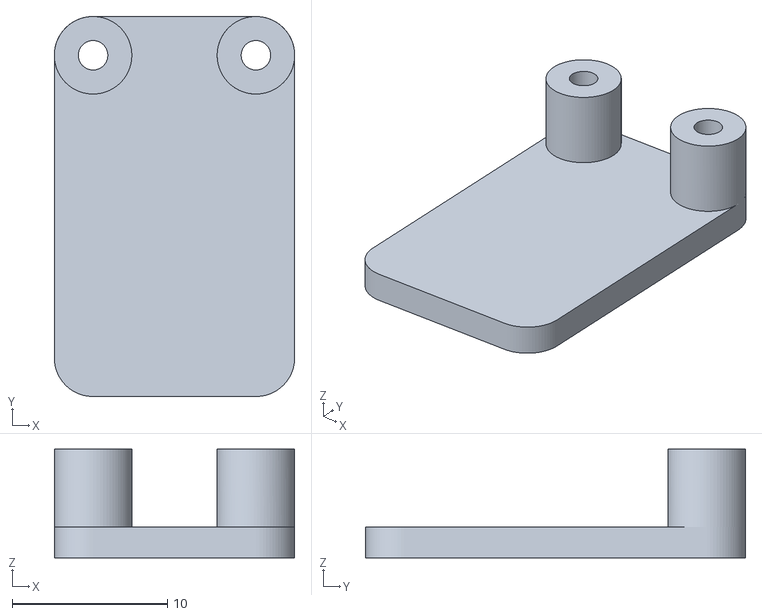
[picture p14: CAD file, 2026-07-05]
3d/basetta ampli.stl
15.5 x 24.5 x 7.00

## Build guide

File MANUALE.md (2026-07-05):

# MANUALE DI REALIZZAZIONE — ALEXO

**Assistente vocale "tipo Alexa" fai-da-te su ESP32-S3.**

Questo manuale spiega **come è fatto Alexo**, sia dal lato dei **collegamenti
elettrici** (cosa si salda a cosa e perché) sia dal lato del **programma** (cosa
fa ogni pezzo di codice). È scritto per essere capito anche senza essere esperti:
ogni concetto difficile è spiegato con parole semplici e con un esempio.

> Questo manuale racconta anche il *perché* delle scelte, non solo il *come*: così,
> se qualcosa nel tuo montaggio è diverso, capisci dove mettere le mani.

---

## Indice

1. [Cos'è Alexo e come "ragiona"](#1-cosè-alexo-e-come-ragiona)
2. [La catena vocale spiegata semplice](#2-la-catena-vocale-spiegata-semplice)
3. [I componenti (la spesa) e a cosa servono](#3-i-componenti-la-spesa-e-a-cosa-servono)
4. [I collegamenti elettrici, pezzo per pezzo](#4-i-collegamenti-elettrici-pezzo-per-pezzo)
5. [Alimentazione e le "trappole" hardware da conoscere](#5-alimentazione-e-le-trappole-hardware-da-conoscere)
6. [Il software: come è organizzato](#6-il-software-come-è-organizzato)
7. [Le impostazioni fondamentali (config.h e secrets.h)](#7-le-impostazioni-fondamentali)
8. [Come funziona il programma, modulo per modulo](#8-come-funziona-il-programma-modulo-per-modulo)
9. [La "macchina a stati": il ciclo di vita di una domanda](#9-la-macchina-a-stati)
10. [La wake word "Okay Nabu" spiegata semplice](#10-la-wake-word-okay-nabu-spiegata-semplice)
11. [Compilare e caricare il firmware](#11-compilare-e-caricare-il-firmware)
12. [Diagnostica e risoluzione problemi](#12-diagnostica-e-risoluzione-problemi)
13. [Come personalizzare Alexo](#13-come-personalizzare-alexo)
14. [Il pannello impostazioni web](#14-il-pannello-impostazioni-web)
15. [La musica: ascoltare la web-radio](#15-la-musica-ascoltare-la-web-radio)

---

## 1. Cos'è Alexo e come "ragiona"

Alexo è un piccolo dispositivo che **ascolta una domanda a voce e risponde a
voce**, come Alexa o Google Home. La differenza è che ce lo siamo costruiti noi,
su un microcontrollore **ESP32-S3**.

Il "cervello" vero e proprio (l'intelligenza artificiale che capisce e risponde)
**non gira dentro Alexo**: gira nel cloud. Alexo da solo è troppo piccolo per
farlo. Quindi Alexo fa il **fattorino**: registra la tua voce, la manda su
Internet a dei servizi specializzati, riceve la risposta e la fa parlare.

**Analogia:** immagina un centralinista. Non sa lui la risposta, ma sa a chi
telefonare per averla, e poi te la riferisce. Alexo è quel centralinista.

L'unica cosa "intelligente" che Alexo fa **da solo, offline**, è accorgersi
quando dici la parola magica ("Okay Nabu") per svegliarsi. Quello sì, lo fa in
casa, senza Internet.

---

## 2. La catena vocale spiegata semplice

Quando fai una domanda, l'informazione passa attraverso una **catena** di
passaggi. Ogni freccia è una "telefonata" via Internet (HTTPS):

```mermaid
flowchart TD
    START(["🗣️ Dici 'Okay Nabu' → Alexo si sveglia (in locale, offline)<br/>in alternativa: click sull'encoder"])
    MIC["🎤 Il microfono registra la tua voce<br/>(finché non fai ~1,5 s di silenzio)"]
    STT["📤 GROQ · Whisper<br/>l'audio diventa TESTO"]
    LLM["🧠 CLAUDE · Anthropic<br/>legge il testo e scrive la RISPOSTA<br/>(può cercare sul web)"]
    TTS["🔊 ELEVENLABS<br/>la risposta-testo diventa VOCE (MP3)"]
    OUT["🔈 L'audio esce dall'altoparlante"]
    DISP["📺 Sul display scorre la conversazione"]

    START --> MIC --> STT -->|testo| LLM -->|risposta| TTS --> OUT
    LLM -. nel frattempo .-> DISP

    classDef cloud fill:#0e2a33,stroke:#00e5ff,color:#dfeef2;
    classDef ui fill:#1a1030,stroke:#ff2ea6,color:#dfeef2;
    class STT,LLM,TTS cloud;
    class DISP ui;
```

Perché tre servizi diversi e non uno solo?

- **Groq/Whisper** è bravissimo a trasformare **voce → testo** (si chiama STT,
  *Speech To Text*). Ed è gratis.
- **Claude** è il cervello: legge il testo e scrive la risposta. È bravo a
  *capire e ragionare*, ma lavora solo col testo, non con l'audio.
- **ElevenLabs** è bravissimo a trasformare **testo → voce** (si chiama TTS,
  *Text To Speech*), con una voce naturale (addirittura clonata dalla voce
  dell'utente).

Ognuno fa il mestiere che sa fare meglio. Alexo li mette in fila.

> **Servono 3 chiavi (API key)**: una per Groq, una per Anthropic (Claude), una
> per ElevenLabs. Sono come password personali per usare quei servizi. Si
> ottengono gratis/registrandosi sui rispettivi siti. Dove si mettono lo vediamo
> nel [capitolo 7](#7-le-impostazioni-fondamentali).

---

## 3. I componenti (la spesa) e a cosa servono

| Pezzo | Modello | A cosa serve (in parole semplici) |
| --- | --- | --- |
| **Cervello elettronico** | ESP32-S3 **N16R8** | Il microcontrollore. È il "computer" che coordina tutto. Ha WiFi integrato, 16 MB di memoria flash (dove sta il programma) e 8 MB di PSRAM (memoria di lavoro, dove tiene l'audio registrato). |
| **Microfono** | **ICS-43434** (I2S) | L'orecchio. È un microfono *digitale*: manda già i numeri, non un segnale analogico da interpretare → più pulito. |
| **Decoder audio** | **VS1003/VS1053** (SPI) | La "scheda audio". Riceve un flusso MP3 (la voce di ElevenLabs, oppure una **web-radio**) e lo trasforma in suono vero. L'ESP32 da solo non saprebbe suonare un MP3. ⚠️ Decodifica **solo MP3** (niente AAC): conta per le radio, vedi [cap. 15](#15-la-musica-ascoltare-la-web-radio). |
| **Amplificatore** | **PAM8302A** | Alza il volume del segnale del VS1053 abbastanza da far suonare l'altoparlante. Da solo il decoder è troppo debole. |
| **Altoparlante** | uno qualsiasi piccolo | La bocca. Emette il suono. |
| **Display** | **ST7735** TFT 1.8" a colori | Lo schermo. Mostra la chat (le tue domande e le risposte) come un teleprompter che scorre. |
| **Anello LED** | **WS2812** 12 LED (NeoPixel) | Le "luci di stato". Cambiano animazione a seconda di cosa sta facendo Alexo (ascolta, pensa, parla). |
| **Manopola** | **Encoder rotativo** KY-040  | Il comando fisico. Si clicca per avviare/fermare, si gira per scorrere la chat o cambiare volume. |

> Nota storica: all'inizio si era provato un microfono analogico **MAX4466** e un
> pulsante separato. Il codice supporta ancora il MAX4466 (basta cambiare
> un'impostazione), ma la versione attuale usa il microfono digitale ICS-43434 e
> l'encoder come unico comando.

---

## 4. I collegamenti elettrici, pezzo per pezzo

> ⚠️ **Regola d'oro:** i numeri dei pin dell'ESP32 li decidiamo noi nel file
> [`include/config.h`](include/config.h). Quel file è l'**unica fonte di
> verità**: se ricabli qualcosa, cambi *solo* lì e tutto il resto del programma
> si adegua da solo. Le tabelle qui sotto rispecchiano i valori attuali di
> `config.h`.

Prima due concetti che tornano sempre:

- **GPIO** = "General Purpose Input/Output", cioè i piedini programmabili
  dell'ESP32. Ognuno ha un numero (es. GPIO14). Alcuni sono "speciali" e vanno
  evitati (lo spieghiamo sotto).
- **Bus SPI / I2S** = "autostrade" di comunicazione. Più dispositivi possono
  condividere la stessa autostrada, ma serve un pilota. Alexo usa **due bus SPI
  separati** apposta (uno per l'audio, uno per il display) così non si intralciano.

### 4.1 Microfono ICS-43434 (bus I2S)

Il microfono digitale parla la lingua **I2S** (tre fili di segnale + alimentazione).

| Pin del microfono | Va a… | Note |
| --- | --- | --- |
| VDD | **3V3** | alimentazione 3,3 V |
| GND | **GND** | massa |
| SCK (clock) | **GPIO5** | il "metronomo" |
| WS (word select)  | **GPIO6** | dice quando è il turno del canale sinistro/destro |
| SD (dati) | **GPIO7** | qui viaggiano i numeri dell'audio |
| L/R | **GND** | messo a massa = il mic usa il canale **sinistro** |

### 4.2 Decoder audio VS1053/VS1003 (bus SPI "audio", detto FSPI)

Questo è il pezzo più delicato da cablare. Condivide 3 fili (SCK, MOSI, MISO)
ma ha 4 fili di controllo tutti suoi.

| Pin del VS1053 | Va a… | A cosa serve |
| --- | --- | --- |
| SCK | **GPIO12** | clock del bus SPI |
| MOSI (SI) | **GPIO11** | dati che vanno *verso* il chip |
| MISO (SO) | **GPIO13** | dati che tornano *dal* chip |
| XCS | **GPIO10** | "chip select" per i **comandi** |
| XDCS | **GPIO21** | "chip select" per i **dati** (il flusso MP3) |
| DREQ | **GPIO18** | il chip dice "sono pronto, dammi altri dati" |
| XRST | **GPIO8** | reset hardware del chip |
| LOUT / ROUT / AGND | → ingresso amplificatore | l'audio analogico che esce |
| Alimentazione | **5V** e GND | |

> **Perché DREQ è su GPIO18 e XRST su GPIO8, e non altrove?** All'inizio erano
> su GPIO47 e GPIO38. Ma il **GPIO38** è collegato al LED di bordo della scheda:
> quel circuito "sporcava" il segnale di reset all'accensione e il chip audio a
> volte non si avviava (partenza "a freddo" inaffidabile). Spostandolo su GPIO8
> il problema è sparito. È un esempio di quanto la scelta dei pin conti.

### 4.3 Amplificatore PAM8302A

| Pin del PAM8302A | Va a… | Note |
| --- | --- | --- |
| A+ / A− (ingresso) | **LOUT/ROUT + AGND del VS1053** | prende il suono debole dal decoder  |
| VCC | **5V** | alimentazione |
| GND | **GND** | |
| SD (shutdown) | **GPIO39** | accende/spegne l'ampli (vedi sotto) |
| uscita + / − | **altoparlante** | |

> **Il trucco del pin SD (GPIO39).** L'amplificatore, quando è acceso e non c'è
> suono, fa un leggero "fruscio" fastidioso. Allora lo teniamo **spento a
> riposo** e lo **accendiamo solo un attimo prima di parlare**. Il pin SD è
> "attivo basso": mettere GPIO39 a livello ALTO = ampli acceso, a livello BASSO =
> ampli muto (consumo quasi zero, niente fruscio). Nel codice lo fa la funzione
> `ampEnable()`.

### 4.4 Display TFT ST7735 (bus SPI "display", detto HSPI — separato!)

| Pin del display | Va a… | Note |
| --- | --- | --- |
| SCLK (SCL) | **GPIO2**  | clock (bus separato dall'audio) |
| MOSI (SDA/DIN) | **GPIO1**  | dati verso il display |
| CS | **GPIO42** | chip select |
| DC (A0/RS) | **GPIO41** | "questo è un comando o un dato?" |
| RST (RES) | **GPIO40** | reset |
| LED/BL (retroilluminazione) | **GPIO14** | accende/spegne la luce dello schermo |
| VCC | **3V3** | |
| GND | **GND** | |

> **Due dettagli furbi sul display:**
> 
> 1. **Bus separato (HSPI):** il display sta su un'autostrada tutta sua, diversa
>    da quella dell'audio. Così, mentre la chat scorre sullo schermo (gestita da
>    un "core" del processore), l'audio non fa singhiozzi (gestito dall'altro
>    core). Sono due lavoratori che non si pestano i piedi.
> 2. **Retroilluminazione su GPIO14:** invece di tenere la luce sempre accesa,
>    la pilotiamo noi. Dopo 2 minuti di inattività Alexo la **spegne** per
>    risparmiare, e la riaccende al primo comando. Il pin assorbe pochissimo
>    (~2 mA), quindi lo colleghiamo direttamente senza transistor.

### 4.5 Anello LED WS2812 (NeoPixel)

| Pin del ring | Va a… |
| --- | --- |
| DIN (dati) | **GPIO48** |
| 5V | **5V** |
| GND | **GND** |

> **Attenzione al filo dati (DIN):** i suoi impulsi elettrici possono
> "disturbare" i fili vicini. Va tenuto **lontano** dai fili del display (SCLK/
> MOSI). Se dà problemi (LED che lampeggiano a caso durante lo scroll), si può
> mettere una resistenza da ~330 Ω in serie sul DIN.

### 4.6 Encoder rotativo (la manopola)

| Pin dell'encoder | Va a… | Note |
| --- | --- | ---- |
| CLK (A) | **GPIO16** | |
| DT (B) | **GPIO15** | |
| SW (pulsante) | **GPIO17** | |
| + | **3V3** | |
| GND | **GND** | |

> Nota: se dopo il montaggio "orario" e "antiorario" risultano **invertiti** (capita
> facilmente scambiando i fili A e B), non è un problema: basta scambiare i due pin
> `CLK` e `DT` in `config.h`.

---

## 5. Alimentazione e le "trappole" hardware da conoscere

### 5.1 Come si alimenta

Il sistema si alimenta dai **5V** (ad esempio da un alimentatore USB). Il microfono
e il display vogliono **3,3 V**; il decoder audio, l'amplificatore e il ring vogliono
**5 V**. Entrambe le tensioni si prendono dalla scheda ESP32 (che ha sia il pin 3V3 sia
il 5V), con la **massa (GND) in comune** a tutto.

> Se alimenti dal pin **5V** della DevKitC-1, verifica sul tuo modello se quel pin è già
> collegato al rail interno o se serve chiudere un ponticello "IN-OUT" sulla scheda (su
> alcuni cloni dual-USB-C il 5V è isolato di default).

### 5.2 I condensatori di disaccoppiamento (importantissimi!)

**Problema scoperto sul campo:** quando i LED del ring si accendono, "succhiano"
corrente a strappi. Questi strappi, viaggiando sull'alimentazione, arrivavano
fino al microfono e lo **sporcavano** di rumore. Risultato: le luci reattive al
suono impazzivano e la registrazione era disturbata.

**Soluzione:** due **condensatori** fanno da "serbatoio d'acqua" che assorbe gli
strappi e tiene stabile la tensione:

- **470 µF** sul VCC del microfono
- **1000 µF** sul 5V del ring LED

> Analogia: è come mettere una cisterna vicino a un rubinetto che viene aperto e
> chiuso di continuo. La cisterna assorbe i colpi e a valle l'acqua resta stabile.

### 5.3 Altre due trappole risolte (utili da sapere)

1. **Il fading dei LED "a scatti".** Impostare la luminosità globale dei NeoPixel
   a un valore basso *quantizza* le sfumature (restano pochi livelli, il fading si
   vede a gradoni). Soluzione: tenere la luminosità globale al **massimo (255)** e
   usare valori bassi **direttamente** nei colori delle animazioni.
2. **Il primo "bip" e poi silenzio.** Il decoder VS1053, quando gli mandi il
   comando `stopSong()` su suoni molto brevi, si "incanta". Soluzione: non usare
   `stopSong()`; invece si mandano i dati del suono seguiti da un po' di
   **silenzio** (byte a zero) che spinge fuori l'ultimo pezzo. Lo stesso trucco
   vale per la voce e per i bip.

---

## 6. Il software: come è organizzato

Il programma è scritto in **C++** con l'ambiente **PlatformIO** (dentro VS Code).
È diviso in tanti file piccoli, ognuno con un compito. Questo si chiama
"modularità": è come una cucina dove ogni cuoco fa un piatto.

```
include/               ← le "etichette" (dichiarazioni) + le impostazioni
  config.h             ← ★ TUTTI i pin e i parametri. Si modifica QUI.
  secrets.example.h    ← modello per le password/chiavi (da copiare in secrets.h)
  *.h                  ← una "etichetta" per ogni modulo sotto

src/                   ← il codice vero e proprio
  main.cpp             ← il DIRETTORE D'ORCHESTRA: coordina tutto
  mic.cpp              ← registra dal microfono
  net.cpp              ← si connette al WiFi
  stt.cpp              ← manda l'audio a Groq → riceve il testo
  llm.cpp              ← manda il testo a Claude → riceve la risposta
  tts.cpp              ← manda la risposta a ElevenLabs → suona la voce
  music.cpp            ← riproduce la web-radio (flusso MP3 → VS1053)
  ui.cpp               ← anima l'anello LED
  gobbo.cpp            ← disegna la chat sul display
  encoder.cpp          ← legge la manopola
  volume.cpp           ← gestisce il volume (e lo ricorda)
  sound.cpp            ← genera i "bip" di conferma
  netlog.cpp           ← invia i log via rete (per leggerli senza cavo USB)
  settings.cpp         ← parametri modificabili "a caldo", salvati in memoria (NVS)
  webui.cpp            ← il web server del pannello impostazioni
  wakeword.cpp         ← riconosce "Okay Nabu" (l'unica IA locale)

data/                  ← file serviti dal web server (via LittleFS)
  index.html           ← la pagina del pannello impostazioni
```

**Due "core" (due cervelli nel processore).** L'ESP32-S3 ha due nuclei di
calcolo. Alexo li usa così:

- **Core 1**: fa la pipeline pesante (registrazione + telefonate a Internet).
- **Core 0**: fa le animazioni (LED, display, lettura encoder).

Perché? Perché le telefonate a Internet **bloccano** chi le fa per qualche
secondo. Se le animazioni fossero sullo stesso core, si congelerebbero. Tenendole
su un core separato, restano fluide anche mentre Alexo "pensa".

---

## 7. Le impostazioni fondamentali

### 7.1 `config.h` — i pin e i comportamenti

È il pannello di controllo. Alcuni esempi di cose che si regolano lì:

- I **numeri dei pin** di ogni componente (capitolo 4).
- `MIC_USE_I2S` → `1` usa il mic digitale, `0` il vecchio analogico.
- `IDLE_REACTIVE` → `1` fa "ballare" i LED col suono quando Alexo è a riposo.
- `REC_SILENCE_MS 1500` → dopo 1,5 s di silenzio la registrazione si chiude da sola.
- `REC_MAX_MS 20000` → non registra mai più di 20 secondi.
- `WAKE_ENABLE 1` → attiva la wake word "Okay Nabu".
- `DISPLAY_SLEEP_MS 120000` → spegne lo schermo dopo 2 minuti di inattività.
- Vari flag di **diagnostica** (`MIC_DIAG`, `WAKE_TEST`, `TFL_SELFTEST`) che
  vedremo nel capitolo 12.

### 7.2 `secrets.h` — le password (NON si condivide!)

Le credenziali WiFi e le 3 chiavi API stanno in un file a parte,
`include/secrets.h`, che **non viene mai messo online** (è escluso da git). Si
crea copiando il modello:

```
include/secrets.example.h   →   copia e rinomina in   →   include/secrets.h
```

E dentro si compilano i valori veri:

```cpp
#define WIFI_SSID        "il-nome-del-tuo-wifi"
#define WIFI_PASSWORD    "la-tua-password"
#define GROQ_API_KEY       "gsk_..."     // per Whisper (voce→testo), gratis
#define ANTHROPIC_API_KEY  "sk-ant-..."  // per Claude (il cervello)
#define ELEVENLABS_API_KEY "sk_..."      // per la voce (testo→voce)
```

> ⚠️ Le chiavi API sono come password: **mai** metterle in file pubblici o
> condividerle. Se una si "brucia", si rigenera dal sito del servizio.

### 7.3 La configurazione critica anti "boot loop"

C'è un dettaglio nel file `platformio.ini` che **non va toccato**. La scheda
N16R8 ha 16 MB di flash, ma il "profilo" standard la crede da 8 MB. Senza queste
righe il dispositivo entra in **boot loop** (si riavvia all'infinito):

```ini
board_upload.flash_size  = 16MB           ; dice la verità sulla dimensione
board_upload.maximum_size = 16777216
board_build.arduino.memory_type = qio_opi ; attiva gli 8 MB di PSRAM
```

Se un giorno vedi solo messaggi strani e continui riavvii sulla seriale, il
sospetto numero uno è questo.

---

## 8. Come funziona il programma, modulo per modulo

### `mic.cpp` — l'orecchio

Registra l'audio dal microfono a **16.000 campioni al secondo** (è la "risoluzione"
che vuole Whisper) e lo mette nella PSRAM (la memoria grande).

Cose intelligenti che fa:

- **Passa-alto ~120 Hz:** un filtro che toglie i rumori bassi (il "rimbombo" e
  la componente continua del microfono), lasciando passare la voce. È il
  segreto che ha reso la registrazione pulita.
- **Stop automatico al silenzio (adattivo):** mentre registri, misura l'energia
  media del suono; se sente 1,5 s di silenzio *dopo* che hai parlato, chiude da
  sola. Così non devi premere "stop". La soglia che distingue "voce" da "silenzio"
  **non è fissa**: si calcola sopra il rumore di fondo stimato in tempo reale
  (`soglia = fondo × margine + minimo`), così si adatta da sola se cambia il
  rumore ambientale (una stanza più o meno rumorosa). Usa la media (RMS) e non il
  picco, perché i rumori impulsivi (un colpo, una folata d'aria sul microfono) fanno
  picchi isolati altissimi che ingannerebbero il picco ma non la media. Questi due
  valori (`margine` e `minimo`) sono regolabili dal
  [pannello web](#14-il-pannello-impostazioni-web).
- **Livello per i LED:** dallo stesso audio calcola quanto "forte" stai parlando,
  per far reagire l'anello luminoso. Usa un "envelope follower" (un valore che
  sale piano e scende piano) per evitare che i LED sfarfallino sui rumori isolati.
- **"Ho sentito voce vera?"** Tiene traccia se durante la registrazione il suono ha
  davvero superato la soglia (`micHeardVoice`). Serve alla difesa anti-fantasma
  (vedi sotto).

#### Il filtro anti-fantasma di Whisper

Ogni tanto capita un **falso avvio** (la wake word che si ri-attiva sulla coda
audio, o un disturbo): parte una registrazione che contiene solo silenzio/rumore.
Il riconoscitore vocale (Whisper), messo davanti al silenzio, **"allucina"**: in
italiano quasi sempre inventa *"Grazie"*, *"Grazie a tutti"* o *"Sottotitoli a cura
di…"*. Il risultato era che Alexo faceva partire una risposta dal nulla.

Due difese (in `main.cpp`):

1. **Se non è stata sentita voce vera**, Alexo torna a riposo **senza nemmeno
   chiamare Whisper** (usa `micHeardVoice`). Taglia il problema alla radice.
2. **Filtro sulle frasi-fantasma:** se comunque la trascrizione è *esattamente* una
   frase-fantasma nota, la scarta in silenzio. La **lista è modificabile dal
   [pannello web](#14-il-pannello-impostazioni-web)**, così ne aggiungi di nuove
   senza ricompilare.

### `net.cpp` — il WiFi

Si collega alla rete di casa usando le credenziali di `secrets.h`. Serve una rete
a **2,4 GHz** (l'ESP32 non parla il 5 GHz).

Fa anche una cosa fondamentale per gli orari: **sincronizza l'orologio via NTP**
(un servizio Internet che dà l'ora esatta), impostando il fuso italiano con il
cambio ora legale automatico. Da qui `nowContextString()` produce la stringa
data/ora (locale + UTC) che finisce nel cervello (`llm.cpp`). Senza NTP, l'ESP32
partirebbe dal 1970 e Claude non saprebbe che ora è.

### `stt.cpp` — da voce a testo (STT)

Prende l'audio registrato (in formato WAV), lo impacchetta in una richiesta web
"multipart" (come allegare un file a un modulo) e lo invia a **Groq**. Groq usa
il modello **Whisper** e restituisce il testo di ciò che hai detto. Alexo estrae
il campo `text` dalla risposta.

### `llm.cpp` — il cervello (Claude)

Il pezzo più "intelligente". Invia il tuo testo all'API di **Anthropic** (modello
`claude-haiku-4-5`, veloce ed economico) e riceve la risposta. Punti chiave:

- **System prompt:** una "istruzione permanente" dice a Claude di essere Alexo,
  di rispondere breve e colloquiale (2-3 frasi, niente elenchi né emoji, perché
  poi va letto ad alta voce).
- **Memoria della conversazione:** conserva gli ultimi 8 messaggi, così puoi fare
  domande di seguito ("e a Milano?" dopo aver chiesto il meteo di Roma). Dopo 2
  minuti di inattività la memoria si azzera (nuova conversazione).
- **Ricerca web:** Claude può cercare su Internet da solo (meteo, notizie,
  prezzi) fino a 3 volte per domanda. Alexo poi legge solo il riassunto.
- **Data e ora reali:** a ogni domanda, Alexo aggiunge al system prompt la data e
  l'ora attuali (locale + UTC), prese dall'orologio sincronizzato via Internet
  (vedi `net.cpp`). Senza, Claude **non sa che ora è adesso** e sbaglierebbe sia
  "che ore sono" sia il calcolo dei fusi delle altre città (che ricava dall'UTC).

### `tts.cpp` — da testo a voce (TTS)

Manda la risposta a **ElevenLabs**, che restituisce un file **MP3** con la voce.
L'MP3 non arriva tutto insieme: arriva "a pezzetti" (streaming) e ogni pezzetto
viene subito passato al decoder VS1053. Così la voce parte prima ancora di aver
scaricato tutto (bassa latenza).

Fa anche una **normalizzazione per la pronuncia**: trasforma i simboli e i formati
che il lettore sbaglierebbe. Esempi: "36°C" → "36 gradi centigradi", "19,5" → "19
virgola 5", "100%" → "100 per cento". (Sul display resta scritto normale, la
trasformazione è solo per la voce.)

Include anche la **lettura degli orari** (funzione `leggiOrario`): "12:30" →
"12 e 30", "00:00" → "mezzanotte", "12:00" → "mezzogiorno", "14:00" → "14 in
punto", "00:30" → "zero 30". Senza, il lettore direbbe "dodici due punti trenta".

### `music.cpp` — la web-radio

Riproduce una **radio via Internet** (un flusso MP3 continuo) sull'altoparlante,
riusando lo stesso decoder VS1053 della voce. Dici *"metti radio Kiss Kiss"* (o un
genere, *"metti musica jazz"*) e Alexo apre lo stream e lo suona finché non lo fermi.

Come funziona in breve:

- Il flusso MP3 arriva "a pezzetti" dalla rete e viene passato di continuo al VS1053
  (come la voce, ma senza fine). Supporta stream **http e https** (le radio italiane
  moderne sono quasi tutte in https).
- Le stazioni sono una **lista modificabile dal [pannello web](#14-il-pannello-impostazioni-web)**
  (nome + parola per chiamarla + indirizzo). Chi le sceglie è o il riconoscimento
  diretto della parola, oppure Claude (con uno strumento apposta) se chiedi un genere.
- Mentre suona, l'anello LED "balla" col ritmo (il microfono sente la cassa).
- ⚠️ **Solo MP3:** il VS1053 non sa decodificare l'AAC né le playlist HLS (`.m3u8`),
  formati usati da molte radio. Per questo non tutte le emittenti funzionano: gli
  indirizzi vanno scelti in formato MP3 (vedi [cap. 15](#15-la-musica-ascoltare-la-web-radio)).

### `ui.cpp` — le luci di stato

Un piccolo programma che gira sul core 0 e disegna sull'anello LED ~40 volte al
secondo. A ogni stato corrisponde un'animazione:

- **pronto (idle):** LED spenti, oppure che "ballano" col suono se `IDLE_REACTIVE`.
- **ascolto:** una barra che si riempie da verde a rosso col volume della voce.
- **penso:** una cometa viola-ciano che gira.
- **parlo:** una pulsazione verde-acqua.
- **errore:** lampeggio rosso.
- **OTA (aggiornamento):** cometa verde.

> Tutte le animazioni sono "basate sul tempo" (`millis()`): restano fluide anche
> se qualche fotogramma salta.

### `gobbo.cpp` — la chat sul display

"Gobbo" è il gergo per il **teleprompter**. Mostra la conversazione ("Tu: …" in
giallo, "Alexo: …" in bianco) e la fa scorrere. Trucchi:

- Disegna tutto prima in una **memoria d'appoggio** e poi lo copia sullo schermo
  in un colpo solo → niente sfarfallio.
- Durante la risposta, **sincronizza lo scorrimento con la voce**: la riga che
  Alexo sta "leggendo" resta più o meno al centro.
- Converte gli accenti italiani (à, è, ì, ò, ù…) nel formato del font del display.
- **Gestisce anche l'encoder** (perché sta sullo stesso core): girando scorri la
  chat, cliccando avvii/fermi.
- **Schermata OTA:** durante un aggiornamento via WiFi mostra una videata dedicata
  in stile HUD verde con la **percentuale grande al centro** e una barra di
  avanzamento (`renderOtaScreen`). La disegna questo task (unico che può toccare lo
  schermo); il codice che riceve l'aggiornamento gli passa solo la percentuale.
- **Copia della chat per il pannello web:** tiene anche una copia leggera degli
  ultimi 40 messaggi (in testo "pulito"), che il [pannello web](#14-il-pannello-impostazioni-web)
  mostra nella sua card "Chat". Un contatore segnala quando arriva un messaggio nuovo,
  così il browser aggiorna la chat **solo a fine messaggio**, senza ricaricare a vuoto.

### `encoder.cpp` — la manopola

Legge la manopola con una libreria dedicata, interrogandola ogni millisecondo su
un task apposta (così non perde scatti). Gestisce **quattro gesti**:

- **click** = avvia / ferma la chat
- **doppio click** = accende/spegne i LED reattivi al suono
- **premuto + giro** = volume
- **giro** = scorri la chat

> Piccola complicazione risolta: la libreria segnala un "click" anche al primo dei
> due click di un doppio. Per distinguerli, il click singolo viene **ritardato di
> ~350 ms**: se entro quel tempo arriva un secondo click è un "doppio", altrimenti
> era un "singolo".

> **Mentre suona la radio i gesti cambiano** (siamo nello stato "musica"): il
> **click** passa alla **stazione successiva**, il **doppio click esce** dalla radio
> e torna alla chat, e il **giro** (nudo o premuto) regola il **volume**. Così scorri
> le emittenti come i preset di un autoradio.

### `volume.cpp` — il volume che si ricorda

Regola il volume del decoder e lo **salva nella memoria permanente (NVS)**, così
sopravvive ai riavvii. Il cambio richiesto dalla manopola (core 0) viene applicato
dal core 1 in modo sicuro.

### `sound.cpp` — i bip di conferma

Genera al volo dei toni (un "bip" acuto per "inizio ascolto", uno grave per
"stop", due gravi per "errore"). Non sono file: sono onde sinusoidali calcolate
sul momento e passate al decoder.

### `netlog.cpp` — leggere i log senza cavo

Quando non hai il cavo USB a portata (o Alexo è già montato e installato), i messaggi
di debug puoi leggerli **via rete**: questo modulo li manda anche lì. Ci si collega con
`telnet alexo.local` (porta 23) e si
leggono da un altro computer. Non disturba l'aggiornamento OTA.

### `settings.cpp` — i parametri che si possono cambiare "a caldo"

Molti valori (soglie del microfono, wake word, volume, voce, personalità di
Claude…) una volta erano "scolpiti" nel codice: per cambiarli bisognava
ricompilare. Ora vivono in una **struttura in memoria** (`gSettings`) che all'avvio
viene **caricata dalla memoria permanente (NVS)**; se non c'è nulla di salvato, usa
i valori di fabbrica scritti in `config.h`. Sono i parametri che si regolano dal
[pannello web](#14-il-pannello-impostazioni-web). "Ripristina default" li riporta
ai valori di fabbrica.

### `webui.cpp` — il pannello web

Un piccolo **server web** (porta 80) che serve la pagina delle impostazioni (il
file `data/index.html`, che vive nella memoria flash tramite un file-system
chiamato **LittleFS**) ed espone una piccola "API" per leggere e salvare i
parametri, per la lettura live del microfono, per fermare la musica e per **mostrare
la chat** nel browser. Vedi il [capitolo 14](#14-il-pannello-impostazioni-web).

---

## 9. La macchina a stati

Il cuore del `main.cpp` è una **macchina a stati**: in ogni momento Alexo si
trova in *uno* stato, e passa al successivo quando succede qualcosa. È come un
gioco dell'oca con caselle fisse.

```mermaid
flowchart TD
    PRONTO["PRONTO<br/>a riposo"] -->|wake word / click| ASCOLTO["ASCOLTO<br/>registra la voce"]
    ASCOLTO -->|stop al silenzio| PENSO["PENSO<br/>Whisper + Claude"]
    PENSO -->|risposta pronta| PARLO["PARLO<br/>ElevenLabs → VS1053"]
    PARLO -->|audio finito| PRONTO
    ASCOLTO -->|no WiFi| ERRORE
    PENSO -->|non capito| ERRORE
    ERRORE -->|bip + msg rosso| PRONTO
```

> A riposo (**PRONTO / idle**) il ring è spento o reattivo al suono.

Nel codice, la funzione `runInteraction()` esegue una singola conversazione d
inizio-a-fine, e la funzione `setState()` aggiorna **insieme** le luci (`ui.cpp`)
e l'intestazione del display (`gobbo.cpp`). Il `loop()` principale, oltre a
lanciare `runInteraction()` quando serve, tiene vivo l'OTA, applica i cambi di
volume e ascolta di continuo il microfono per la wake word.

> C'è anche uno stato in più, **MUSICA**: quando chiedi una radio, Alexo entra qui
> e ci resta a suonare finché non lo fermi (doppio click o dal pannello). In questo
> stato la manopola comanda la radio (vedi [`encoder.cpp`](#encodercpp--la-manopola)),
> non la chat.

---

## 10. La wake word "Okay Nabu" spiegata semplice

Questa è l'**unica intelligenza che gira dentro Alexo**, senza Internet. Serve a
farlo svegliare quando dici la parola magica, senza dover toccare la manopola.

**Come fa a "sentire" una parola senza capire il linguaggio?** Usa una minuscola
rete neurale (un "modello" già addestrato) che gira grazie a **TensorFlow Lite
Micro**, una versione dell'IA fatta apposta per i chip piccoli.

Il percorso, semplificato:

```mermaid
flowchart TD
    A["🎤 Audio continuo dal microfono"]
    B["Frontend<br/>trasforma l'audio in 40 numeri ogni 10 ms<br/>(le frequenze del momento, come un equalizzatore)"]
    C["Modello (rete neurale)<br/>quanto assomiglia a 'Okay Nabu'?<br/>→ un valore 0..255"]
    D{"Media su 5 misure<br/>sopra la soglia?"}
    E["🚀 Avvia la chat<br/>(come un click della manopola)"]

    A --> B --> C --> D
    D -->|sì, È LEI| E
    D -->|no| A
```

**Perché "Okay Nabu" e non "Alexo"?** Perché "Okay Nabu" è un modello **già
pronto** (scaricato, molto preciso) e si pronuncia bene. Le parole
inglesi provate prima non andavano ("hey jarvis" non veniva colto per l'accento,
"alexa" scattava su qualsiasi parola che finiva in "-xa"). La parola **"Alexo"
personalizzata** è il prossimo upgrade: bisogna *addestrare* un modello nuovo (si
fa online con Google Colab, usando voci sintetiche, in circa mezz'ora) e poi
sostituire il file del modello.

**Tre lezioni imparate** (utili se ci metti mano):

1. Il modello è di tipo *streaming*: vuole un **flusso continuo** di audio, senza
   pause. Se metti dei ritardi tra una lettura e l'altra, non riconosce più nulla.
2. **Troppo guadagno satura** e peggiora il riconoscimento. Meglio non esagerare.
3. **Dopo ogni conversazione** bisogna "svuotare" l'audio accumulato
   (`micFlush()` + `wakeReset()`), altrimenti Alexo si ri-sveglia da solo sentendo
   la propria risposta appena finita di parlare.

> Il procedimento per **addestrare una wake word personalizzata** (es. "Alexo") si fa
> online con Google Colab, usando voci sintetiche, in circa mezz'ora; poi si sostituisce
> il file del modello nel progetto.

---

## 11. Compilare e caricare il firmware

Il progetto si compila con **PlatformIO**. I comandi qui sotto sono `pio` "puro"; se
usi PlatformIO dentro VS Code trovi gli stessi pulsanti (Build / Upload) nell'interfaccia.

**Compilare** (creare il firmware dai sorgenti):

```
pio run -e esp32-s3-devkitc-1
```

### Primo caricamento: via USB

La **prima volta** (scheda nuova) si carica **via cavo USB**: colleghi l'ESP32 al
computer e lanci l'upload sulla porta seriale.

```
pio run -e esp32-s3-devkitc-1 -t upload
```

> Su Windows, se `pio` non è nel PATH, chiamalo col percorso completo
> (`%USERPROFILE%\.platformio\penv\Scripts\pio.exe`). Prima di caricare via USB chiudi
> l'eventuale monitor seriale, altrimenti la porta risulta occupata ("Accesso negato").

### Caricamenti successivi: via WiFi (OTA), se preferisci

Una volta che Alexo è sul WiFi, puoi aggiornarlo **senza cavo**, "over the air": comodo
se è già installato o in un punto scomodo da raggiungere. Nel `platformio.ini` si
impostano le righe per l'upload OTA verso `alexo.local` (il nome di rete di Alexo) al
posto di quelle per l'USB. La board dev'essere accesa, connessa al WiFi e a riposo.

Durante l'aggiornamento OTA, sul display appare una **schermata dedicata** (HUD verde con
la percentuale grande al centro e la scritta "NON SPEGNERE"), così vedi l'avanzamento a
colpo d'occhio.

> **Se hai modificato la pagina del pannello web** (`data/index.html`), oltre al firmware
> devi caricare anche il file-system con `... -t uploadfs`. Via OTA, aspetta che
> `alexo.local` torni online dopo il riavvio del firmware prima di lanciarlo. Vedi il
> [capitolo 14](#14-il-pannello-impostazioni-web).

**Backup pronti:** nella cartella [`firmware_demo/`](firmware_demo/) ci sono versioni
`.bin` già compilate e funzionanti, per tornare in fretta a una build buona se un
esperimento va storto.

---

## 12. Diagnostica e risoluzione problemi

### 12.1 Leggere cosa dice Alexo

- **Via USB:** monitor seriale a 115200 baud sulla porta dell'ESP32.
- **Via WiFi** (senza cavo): `telnet alexo.local` (porta 23) — vedi `netlog.cpp`.

### 12.2 I flag di diagnostica in `config.h`

Mettendo uno di questi a `1` (e ricaricando il firmware), Alexo entra in una modalità
speciale che **non avvia la chat** ma resta comunque aggiornabile. Per uscire: si
rimette a `0` e si ricarica.

| Flag | Cosa fa |
| --- | --- |
| `MIC_DIAG` | Misura il rumore del microfono e stampa i livelli: serve a scegliere il guadagno giusto e a capire se un rumore è "software" (bassa frequenza, si filtra) o "hardware" (massa/EMI). |
| `TFL_SELFTEST` | Prova che il motore di IA (TensorFlow Lite Micro) funzioni, con un modellino di test. |
| `WAKE_TEST` | Prova la catena della wake word e stampa la "probabilità" mentre parli: utile per tarare la soglia. |

### 12.3 Problemi tipici e prima cosa da controllare

| Sintomo | Sospetto numero uno |
| --- | --- |
| Si riavvia all'infinito, solo messaggi ROM | Config anti boot-loop in `platformio.ini` (cap. 7.3) |
| PSRAM = 0 byte | Manca `memory_type = qio_opi` |
| Non si connette al WiFi | Rete a 5 GHz (serve 2,4 GHz) o credenziali sbagliate in `secrets.h` |
| Trascrive "Grazie" a caso / riparte una chat da sola | Falso avvio + allucinazione di Whisper sul silenzio — ora filtrata (skip se non sente voce + lista frasi-fantasma nel pannello) |
| I LED lampeggiano a vuoto a riposo | Manca il filtro passa-alto o i condensatori di disaccoppiamento |
| Solo il primo bip suona | Uso di `stopSong()` su toni brevi (cap. 5.3) |
| Il chip audio a freddo non parte | Reset (XRST) disturbato — vedi scelta GPIO8 (cap. 4.2) |
| Alexo si risveglia da solo dopo aver parlato | Manca `micFlush()`/`wakeReset()` a fine interazione |

### 12.4 Il metodo: isola una variabile

Quando qualcosa si rompe, **cambia una cosa alla volta** e verifica. Non toccare
tre parametri insieme: se poi funziona (o non funziona) non sai quale è stato.
È il modo più veloce per trovare il colpevole.

---

## 13. Come personalizzare Alexo

> 💡 **La via più comoda:** quasi tutto ciò che segue si può ormai cambiare dal
> [pannello web](#14-il-pannello-impostazioni-web) (voce, voce alternativa +
> trigger, modello e personalità di Claude, soglie mic/wake, volume, easter-egg),
> **senza ricompilare**. Sotto restano i riferimenti nel codice per chi vuole
> cambiare i valori di *fabbrica* o toccare cose non esposte nel pannello.

Tutto senza toccare la logica, solo pochi valori:

- **Cambiare la voce (default di fabbrica):** in [`include/config.h`](include/config.h)
  ci sono `ELEVEN_VOICE_DEF`, la voce alternativa `ELEVEN_VOICE_ALT_DEF` e la
  parola-trigger `VOICE_TRIGGER_DEF`. (Dal pannello web cambi i valori *attivi*
  senza ricompilare, e le parole-trigger possono essere più d'una.)
- **Rendere Alexo più "intelligente" (default):** `LLM_MODEL_DEF` in `config.h`.
  Tre scelte: `claude-haiku-4-5` (veloce/economico), `claude-sonnet-5` (equilibrato)
  e `claude-opus-4-8` (il più intelligente, più lento/costoso). Dal pannello lo
  cambi al volo. Per la voce conviene la velocità → Haiku o Sonnet.
- **Cambiare la personalità (default):** `SYSTEM_PROMPT_DEF` in `config.h` (o dal
  pannello). È il testo che descrive chi è Alexo e come deve rispondere.
- **Regolare i tempi/soglie di registrazione:** `REC_SILENCE_MS`,
  `REC_SILENCE_MARGIN`, `REC_SILENCE_FLOOR`, `REC_MAX_MS` in `config.h` (i primi
  tre anche dal pannello).
- **Luci a riposo sì/no:** `IDLE_REACTIVE` in `config.h` (o dal pannello / doppio
  click encoder).
- **Comportamento LED reattivi (default):** `MIC_LVL_MARGIN_DEF`/`MIC_LVL_FLOOR_DEF`
  (soglia), `MIC_LVL_ATTACK_DEF` (reattività/salita) e `MIC_LVL_RELEASE_DEF`
  (permanenza/discesa) in `config.h` — tutti anche dal pannello.
- **Termini dell'easter-egg:** `EGG_TERMS_DEF` in `config.h` (o dal pannello).
- **Cambiare la wake word:** si sostituisce il file del modello `src/wake_model.h`
  (con quello di un'altra parola) e si aggiornano i parametri `WAKE_*` in `config.h`.
  Per addestrare una parola tutta tua vedi la nota in fondo al [capitolo 10](#10-la-wake-word-okay-nabu-spiegata-semplice).

---

## 14. Il pannello impostazioni web

Alexo ha un **pannello di controllo via browser**: apri `http://alexo.local/` da
telefono o PC collegati alla stessa rete WiFi. Da lì regoli i parametri **senza
ricompilare né ricaricare il firmware** — cambi un valore, premi "Salva", ed è
subito attivo e memorizzato (sopravvive ai riavvii).

### A cosa serve (la comodità vera)

Prima, per tarare (per esempio) la sensibilità al rumore di fondo, il ciclo era:
*modifica il codice → ricompila → ricarica → collega il Telnet → leggi*.
Adesso è: *sposti uno slider dal telefono e guardi l'effetto in tempo reale*.

### Cosa puoi regolare

- **Microfono · stop-al-silenzio · LED:** dopo quanti ms di silenzio chiudere la
  registrazione, il margine e il minimo della soglia adattiva (quelli che rendono
  Alexo robusto al rumore di fondo), le soglie dei LED reattivi (margine e minimo di
  accensione), la **reattività** (quanto in fretta i LED si accendono) e la
  **permanenza** (quanto in fretta si spengono), e l'accensione/spegnimento
  dell'effetto luminoso a riposo.
- **Wake word "Okay Nabu":** guadagno, soglia di attivazione, finestra della media
  (quanto dev'essere "sicuro" prima di svegliarsi).
- **Audio:** volume; la **voce** di default (Voice ID ElevenLabs); la **voce
  alternativa** e le sue **parole-trigger** (più d'una, separate da virgola: se la
  frase inizia con una di quelle, Alexo risponde con l'altra voce).
- **Cervello:** il **modello** di Claude (haiku = veloce, opus = più intelligente)
  e la **personalità** (il testo che descrive chi è Alexo e come deve rispondere).
- **Easter egg:** i **termini trigger** (separati da virgola) che fanno scattare
  la frase scherzosa; lascia vuoto per disattivarlo.
- **Filtro anti-fantasma (Whisper):** la lista delle **frasi-fantasma** da scartare
  (quelle che Whisper inventa sul silenzio, tipo "Grazie"); ne aggiungi di nuove se
  ne spunta qualcuna. Lascia vuoto per disattivare il filtro.
- **Musica (web-radio):** la **lista delle stazioni**, una per riga nel formato
  `parola | nome | indirizzo` (la *parola* è quella che dici, es. "virgin"; il *nome*
  è quello che appare a schermo; l'*indirizzo* è lo stream MP3). C'è anche un pulsante
  **"⏹ Ferma musica"** e lo stato di riproduzione. Dettagli su come scegliere gli
  indirizzi giusti nel [capitolo 15](#15-la-musica-ascoltare-la-web-radio).

### La lettura live del microfono (il pezzo forte)

In cima alla pagina c'è un riquadro che mostra, aggiornati ogni secondo:

- il **livello** di suono che il mic sente in questo momento,
- il **rumore di fondo** stimato da Alexo,
- la **soglia** di accensione (una tacca sulla barra),
- la **probabilità wake** (quanto "assomiglia" a Okay Nabu mentre parli),
- più WiFi e memoria libera.

Così tari le soglie **guardandole muoversi** — per esempio introduci un rumore di
fondo (musica, chiacchiericcio, un elettrodomestico), vedi dove si posiziona il
livello, e regoli i parametri sotto quel valore. Non serve più la modalità
`MIC_DIAG` col Telnet.

### La chat nel browser

Il pannello ha anche una card **"Chat"** che mostra la **stessa conversazione che
scorre sul display** (le tue domande e le risposte di Alexo, ultimi 40 messaggi), ma
a tutta larghezza e comoda da leggere/copiare dal telefono. Si aggiorna **da sola a
ogni nuovo messaggio** (non a intervalli fissi: un piccolo "contatore" avvisa il
browser solo quando c'è qualcosa di nuovo, così non ricarica a vuoto). È in **sola
lettura** — serve a *rivedere* la conversazione, non a scrivere da lì. La chat parte
vuota dopo un riavvio (come lo storico sul display, non è memorizzata).

### Come funziona sotto (in parole semplici)

- La pagina (`data/index.html`) è un file salvato nella flash tramite **LittleFS**.
  Il server web (`webui.cpp`) la serve al browser e risponde a delle richieste
  "API" per leggere/scrivere i valori.
- I valori vivono in `gSettings` (`settings.cpp`) e vengono **salvati in NVS**
  (la memoria permanente), così restano dopo lo spegnimento.
- Il server è "sincrono": mentre Alexo sta gestendo una domanda (registra o parla
  con Internet) il pannello per qualche secondo non risponde. È normale: il
  pannello si usa quando Alexo è a riposo.

### ⚠️ Aggiornare la pagina = due passi

Se modifichi **solo il codice** (`.cpp`/`.h`) basta il solito upload del firmware.
Ma se modifichi **la pagina** `data/index.html`, devi caricare *anche* il
file-system:

```
# 1) firmware
pio run -e esp32-s3-devkitc-1 -t upload
# 2) pagina (LittleFS)
pio run -e esp32-s3-devkitc-1 -t uploadfs
```

> Nota: se carichi via WiFi (OTA), dopo il punto 1 il dispositivo si riavvia; aspetta
> che `alexo.local` sia di nuovo raggiungibile prima di lanciare il punto 2.

---

## 15. La musica: ascoltare la web-radio

Oltre a rispondere alle domande, Alexo sa fare da **radio via Internet**: chiedi una
stazione o un genere e la suona sull'altoparlante.

### Come si usa

- **A voce:** *"metti radio Kiss Kiss"*, *"metti musica jazz"*, *"metti Virgin"*.
  Se dici una parola presente nella lista delle stazioni, parte quella; se chiedi un
  genere generico, è **Claude** a scegliere una radio adatta.
- **Mentre suona, con la manopola:**
  - **click** → stazione **successiva** (scorri le emittenti come i preset di un'autoradio)
  - **doppio click** → **esci** dalla radio e torna alla chat
  - **giro** → **volume** (a zero, l'amplificatore si spegne del tutto: niente fruscio)
- **Dal pannello web:** il pulsante **"⏹ Ferma musica"**.

### Le stazioni (e come aggiungerne)

La lista si modifica dal [pannello web](#14-il-pannello-impostazioni-web), una
stazione per riga:

```
virgin | Virgin Radio | http://icecast.unitedradio.it/Virgin.mp3
jazz   | Jazz          | http://listen.181fm.com/181-classicaljazz_128k.mp3
```

`parola | nome | indirizzo`. La *parola* è quella che pronunci; il *nome* appare a
schermo; l'*indirizzo* è il flusso della radio.

### ⚠️ La regola d'oro: solo indirizzi MP3

Il decoder VS1053 sa suonare **solo l'MP3**. Molte radio però trasmettono in **AAC**
o come **playlist HLS** (`.m3u8`): quelle **non funzionano**, anche se l'indirizzo
sembra giusto. È il motivo per cui alcune emittenti "famose" vanno scartate: non è un
difetto di Alexo, è il formato sbagliato. Quando cerchi un nuovo indirizzo, verifica
che sia uno stream **MP3** diretto.

### Perché alcune radio "gracchiano" (nota onesta)

Può capitare che una radio, pur essendo MP3 e pur partendo, si senta **a tratti**
mentre un'altra (identica come formato) vada liscia. In quel caso il problema **non è
Alexo**: è **come quel server consegna i dati** sulla rete WiFi. Alcuni server
"spingono" un cuscinetto di dati in anticipo (e reggono bene), altri mandano lo
stretto necessario in tempo reale (e al minimo intoppo del WiFi si sente a scatti).
La cosa pratica da fare è **tenere nella lista solo le radio che nella tua rete
suonano bene** (il log via Telnet mostra nome e bitrate di ognuna, utile per provarle).

> **Cosa NON si può fare:** Spotify, Amazon Music e Apple Music **non** sono
> accessibili (usano protocolli chiusi e protezioni anti-copia). E niente "metti la
> canzone X dell'artista Y" a comando: le web-radio trasmettono un palinsesto, non
> singoli brani a richiesta.

---

*Manuale del progetto Alexo. Tutti i pin e i parametri citati stanno in
[`include/config.h`](include/config.h), l'unica fonte di verità da modificare.*

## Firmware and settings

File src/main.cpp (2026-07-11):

// ============================================================================
//  ALEXO - Assistente vocale (firmware principale)
//
//  Flusso: tieni premuto -> ASCOLTO (registra) -> PENSO (Whisper + Claude)
//          -> PARLO (ElevenLabs -> VS1053) -> riposo.
//
//  Due core: il loop (core 1) fa la pipeline; le animazioni del ring girano
//  su un task dedicato (core 0, vedi ui.cpp), cosi' restano fluide anche
//  mentre il core 1 e' bloccato sulle chiamate di rete.
// ============================================================================

#include <Arduino.h>
#include <SPI.h>
#include <ArduinoOTA.h>
#include <Adafruit_GFX.h>
#include <Adafruit_ST7735.h>
#include <Adafruit_NeoPixel.h>
#include <VS1053.h>

#include "config.h"
#include "mic.h"
#include "net.h"
#include "stt.h"
#include "llm.h"
#include "tts.h"
#include "ui.h"
#include "sound.h"
#include "gobbo.h"
#include "encoder.h"
#include "volume.h"
#include "netlog.h"
#include "wakeword.h"
#include "tfltest.h"
#include "settings.h"
#include "webui.h"
#include "music.h"

// --- Voce alternativa -------------------------------------------------------
// Se la tua frase INIZIA con la parola-trigger, Alexo risponde con la voce
// alternativa invece di quella di default (vedi tts.cpp). Ora sono RUNTIME:
// gSettings.voiceIdAlt / gSettings.voiceTrigger (modificabili dal pannello web);
// i default di fabbrica stanno in config.h (ELEVEN_VOICE_ALT_DEF/VOICE_TRIGGER_DEF).

// --- Periferiche ------------------------------------------------------------
//  Il TFT sta su un bus SPI DEDICATO (HSPI), separato dal VS1053 (bus globale
//  SPI = FSPI): cosi' lo scroll della chat (core 0) non litiga col feed audio
//  (core 1). MISO non serve al display (sola scrittura) -> -1.
SPIClass tftSPI(HSPI);
Adafruit_ST7735 display(&tftSPI, TFT_CS_PIN, TFT_DC_PIN, TFT_RST_PIN);
Adafruit_NeoPixel ring(LED_RING_COUNT, LED_RING_PIN, NEO_GRB + NEO_KHZ800);

// Sottoclasse diagnostica: nella libreria `read_register` e' protected. La
// esponiamo per leggere i registri SCI del VS1053 e mostrarli sul display
// (cosi' si diagnostica senza la seriale). VS1053Diag E' un VS1053 a tutti gli
// effetti -> nessun'altra parte del codice cambia.
class VS1053Diag : public VS1053 {
public:
  VS1053Diag(uint8_t cs, uint8_t dcs, uint8_t dreq) : VS1053(cs, dcs, dreq) {}
  uint16_t readReg(uint8_t r) { return read_register(r); }
  // Legge un registro SCI SENZA attendere DREQ (read_register fa busy-wait su
  // DREQ e si impiccherebbe). Serve a diagnosticare quando DREQ e' basso: se il
  // chip risponde lo stesso, e' VIVO e alimentato -> il guasto e' SOLO la linea
  // DREQ. Se torna 0000/FFFF, il chip non risponde (alimentazione/reset).
  uint16_t readRegNoWait(uint8_t r) {
    control_mode_on();
    SPI.write(3); SPI.write(r);
    uint16_t v = ((uint16_t)SPI.transfer(0xFF) << 8) | SPI.transfer(0xFF);
    control_mode_off();
    return v;
  }
};
VS1053Diag player(VS1053_XCS_PIN, VS1053_XDCS_PIN, VS1053_DREQ_PIN);

// Istante (millis) in cui e' finito l'ultimo AUDIO dall'altoparlante (musica O
// voce/TTS). Subito dopo, la coda acustica della cassa rientra nel mic e puo'
// innescare un avvio spurio (falso wake o trigger che sfugge): per
// ~AUDIO_COOLDOWN_MS ignoriamo OGNI avvio (wake e click).
static uint32_t g_audioEndMs = 0;
static const uint32_t AUDIO_COOLDOWN_MS = 1500;

// --- Stato ------------------------------------------------------------------
bool tftOk = false;
bool vsOk  = false;
bool micOk = false;

// Condizione di stop della registrazione: registra finche' NON arriva un click
// di stop dall'encoder (toggle). Domani il wake-word/silenzio prenderanno il
// posto di questo predicato senza toccare il resto della pipeline.
static bool recKeepGoing() { return !gobboStopRequested(); }

// Cambia stato: aggiorna SIA il ring (animazioni) SIA l'header del TFT.
static inline void setState(AlexoState s) { uiSetState(s); gobboSetState(s); }

// Allucinazioni tipiche di Whisper sul silenzio/rumore (italiano): quando la
// registrazione non contiene voce, Whisper "inventa" queste frasi. Le scartiamo
// per non far ripartire una chat col fantasma "Grazie". La lista e' editabile dal
// pannello web (gSettings.hallucTerms, separata da virgola). Confronto sul testo
// ripulito (minuscolo, senza punteggiatura/spazi ai bordi), match ESATTO su una
// delle frasi in lista (o testo vuoto).
static bool isAllucinazione(const String &testo) {
  String s = testo; s.toLowerCase(); s.trim();
  while (s.length() && strchr(".!?,;:- ", s[s.length() - 1])) s.remove(s.length() - 1);
  s.trim();
  if (s.length() == 0) return true;
  const String &csv = gSettings.hallucTerms;
  int start = 0;
  while (start <= (int)csv.length()) {
    int comma = csv.indexOf(',', start);
    if (comma < 0) comma = csv.length();
    String term = csv.substring(start, comma);
    term.trim(); term.toLowerCase();
    if (term.length() > 0 && s.equals(term)) return true;
    start = comma + 1;
  }
  return false;
}

// Confronta 't' (GIA' minuscolo) con un elenco di termini separati da virgola
// (es. "bene, ok, ciao"). contains=false -> match se t INIZIA con un termine
// (voce alternativa); contains=true -> match se t CONTIENE un termine (easter-egg).
// Termini vuoti ignorati; elenco vuoto -> nessun match (funzione disattivata).
static bool matchAnyTerm(const String &t, const String &csv, bool contains) {
  int start = 0;
  while (start <= (int)csv.length()) {
    int comma = csv.indexOf(',', start);
    if (comma < 0) comma = csv.length();
    String term = csv.substring(start, comma);
    term.trim(); term.toLowerCase();
    if (term.length() > 0 && (contains ? (t.indexOf(term) >= 0) : t.startsWith(term)))
      return true;
    start = comma + 1;
  }
  return false;
}

// RISPOSTA PERSONALIZZATA: se il trigger (gSettings.replyTrigger) e' valorizzato e la
// domanda lo CONTIENE (confronto minuscolo), torna il testo fisso (gSettings.replyText)
// e si salta l'AI. Trigger vuoto = disattivato (risponde l'AI). Per scherzi/riprese.
static String customReplyMatch(const String &testo) {
  String trig = gSettings.replyTrigger; trig.trim(); trig.toLowerCase();
  if (trig.isEmpty()) return "";
  String tl = testo; tl.toLowerCase();
  if (tl.indexOf(trig) >= 0) return gSettings.replyText;
  return "";
}

// --- Display ----------------------------------------------------------------
//  Splash di stato durante il boot (prima che il gobbo prenda il controllo del
//  TFT). Disegno diretto sul TFT: qui siamo ancora single-task (solo setup()).
void tftStatus(const char *line1, const char *line2 = nullptr) {
  if (!tftOk) return;
  display.fillScreen(ST77XX_BLACK);
  display.setTextSize(2);
  display.setTextColor(ST77XX_CYAN);
  display.setCursor(0, 0);
  display.println("ALEXO");
  display.setTextSize(1);
  display.setTextColor(ST77XX_WHITE);
  display.setCursor(0, 30);
  display.println(line1);
  if (line2) { display.setCursor(0, 42); display.println(line2); }
}

static void setRingSolid(uint8_t r, uint8_t g, uint8_t b) {
  for (int i = 0; i < LED_RING_COUNT; i++) ring.setPixelColor(i, r, g, b);
  ring.show();
}

// --- Amplificatore PAM8302A (SD attivo basso: HIGH = acceso, LOW = muto) -----
//  Acceso solo quando c'e' audio (bip + voce); muto a riposo -> niente fruscio
//  Class-D. Lo accendiamo un attimo PRIMA dell'audio (il pop cade nel silenzio).
//  NON static: lo chiama anche music.cpp per rispegnerlo a volume 0 mentre suona.
void ampEnable(bool on) {
#if AMP_SD_PIN >= 0
  digitalWrite(AMP_SD_PIN, on ? HIGH : LOW);
  if (on) delay(20);   // breve assestamento dell'ampli prima di mandare audio
#endif
}

// --- Gestione errore (feedback + ritorno a riposo) --------------------------
static void fail(const char *msg) {
  Serial.printf(">> %s\n", msg);
  setState(ST_ERROR);
  gobboPrint(String("[") + msg + "]");
  if (vsOk) { ampEnable(true); soundError(player); delay(50); ampEnable(false); }
  delay(1200);
  setState(ST_IDLE);
}

// --- Splash futuristico all'accensione (TFT HUD + ring "carica") ------------
#if SPLASH_BOOT
static void bootSplash() {
  if (!tftOk) return;
  const int W = TFT_WIDTH, H = TFT_HEIGHT;            // 128 x 160
  const uint16_t BLK = ST77XX_BLACK;
  const uint16_t CY  = display.color565(0, 255, 255); // cyan acceso
  const uint16_t CYd = display.color565(0, 70, 85);   // cyan tenue (griglia)
  const uint16_t CYm = display.color565(0, 150, 170); // cyan medio
  const uint16_t MAG = display.color565(255, 0, 170); // accento magenta

  display.fillScreen(BLK);

  // 1) Scanline che scorre dall'alto in basso lasciando una griglia tenue
  for (int y = 0; y < H; y += 4) {
    display.drawFastHLine(0, y, W, CYd);
    display.drawFastHLine(0, y + 2, W, CY);
    delay(6);
    display.drawFastHLine(0, y + 2, W, BLK);
  }
  for (int x = 0; x <= W; x += 16) display.drawFastVLine(x, 0, H, CYd);

  // 2) Parentesi angolari stile HUD
  const int b = 12;
  display.drawFastHLine(2, 2, b, CY);          display.drawFastVLine(2, 2, b, CY);
  display.drawFastHLine(W - 2 - b, 2, b, CY);  display.drawFastVLine(W - 3, 2, b, CY);
  display.drawFastHLine(2, H - 3, b, CY);      display.drawFastVLine(2, H - 3 - b, b, CY);
  display.drawFastHLine(W - 2 - b, H - 3, b, CY); display.drawFastVLine(W - 3, H - 3 - b, b, CY);

  // 3) "Reattore": cerchi concentrici che si espandono + punto che gira sul ring
  const int cx = W / 2, cy = 52;
  for (int r = 3; r <= 36; r += 3) {
    display.drawCircle(cx, cy, r, (r % 6 == 0) ? CY : CYd);
    int idx = (r / 3) % LED_RING_COUNT;
    ring.clear();
    ring.setPixelColor(idx, 0, 45, 55);
    ring.setPixelColor((idx + 1) % LED_RING_COUNT, 0, 14, 18);
    ring.show();
    delay(28);
  }
  display.fillCircle(cx, cy, 6, CY);
  display.drawCircle(cx, cy, 10, CYm);

  // 4) "ALEXO" lettera per lettera (con ombra), poi sottotitolo
  display.setTextSize(3);
  const char *name = "ALEXO";
  const int chW = 18, tw = 5 * chW, tx = (W - tw) / 2, ty = 96;
  for (int i = 0; i < 5; i++) {
    display.setTextColor(CYd); display.setCursor(tx + i * chW + 1, ty + 1); display.write(name[i]);
    display.setTextColor(CY);  display.setCursor(tx + i * chW,     ty);     display.write(name[i]);
    ring.clear();
    for (int k = 0; k <= i * 2 && k < LED_RING_COUNT; k++) ring.setPixelColor(k, 0, 38, 48);
    ring.show();
    delay(130);
  }
  display.setTextSize(1);
  display.setTextColor(CYm);
  const char *sub = "ASSISTENTE VOCALE";
  display.setCursor((W - (int)strlen(sub) * 6) / 2, ty + 26);
  display.print(sub);

  // 5) Barra di avanzamento + ring che "carica" in proporzione
  const int bx = 12, by = 144, bw = W - 24, bh = 7;
  display.drawRect(bx, by, bw, bh, CYm);
  display.setTextColor(ST77XX_WHITE);
  display.setCursor(bx + 14, by - 11); display.print("AVVIO SISTEMA");
  for (int p = 0; p <= bw - 4; p += 3) {
    display.fillRect(bx + 2, by + 2, p, bh - 4, CY);
    int lit = (p * LED_RING_COUNT) / (bw - 4);
    ring.clear();
    for (int k = 0; k < lit && k < LED_RING_COUNT; k++) ring.setPixelColor(k, 0, 32, 42);
    ring.show();
    delay(10);
  }

  // 6) "PRONTO" + pulse del ring che svanisce
  display.setTextColor(MAG);
  //display.setCursor(bx + bw - 42, by - 11); display.print("PRONTO");
  display.setCursor(bx + bw - 42, by - 11); display.print("");
  for (int v = 60; v >= 0; v -= 6) {
    for (int k = 0; k < LED_RING_COUNT; k++) ring.setPixelColor(k, 0, v, (uint8_t)(v * 1.2f));
    ring.show();
    delay(22);
  }
  ring.clear(); ring.show();
  delay(250);
}
#endif

// Avvia una stazione radio: mostra il nome, stato ST_MUSIC (ring reattivo), suona
// finche' non si ferma, poi ritorno PULITO a riposo (mute ampli, flush anti
// falso-wake, finestra di raffreddamento). Usata sia dal match locale (lista del
// pannello) sia dal fallback di Claude (catalogo). L'ampli e' gia' acceso (viene
// dalla fase di ascolto di runInteraction).
static void playStation(const MusicStation *st) {
  // Copio url/nome in String locali: la sorgente (s_mHit / catalogo) verrebbe
  // riusata da musicStationGet durante il seek.
  String url = st->url, nome = st->nome;
  // Indice nella lista del pannello per il seek premuto+giro; -1 se la stazione
  // non e' in lista (es. scelta da Claude dal catalogo): il primo seek entrera'
  // allora dagli estremi della lista.
  int idx = musicStationIndexOf(url.c_str());

  // A volume MUTO (0) spengo l'ampli: la musica e' comunque silenziosa e cosi'
  // sparisce il "macinio"/ronzio Class-D che il mic sentirebbe. Se non muto,
  // l'ampli e' gia' acceso dalla fase di ascolto.
  ampEnable(!volumeIsMuted());
  setState(ST_MUSIC);
  gobboClearStopRequest();

  // Loop di stazioni: musicPlay ritorna 0 = stop/fine, oppure il delta del seek
  // (premuto+giro) -> passo alla stazione prec./succ. della lista e riparto.
  for (;;) {
    Serial.printf(">> MUSICA: %s (%s)\n", nome.c_str(), url.c_str());
    gobboPrint(String("\xE2\x99\xAA ") + nome);   // "♪ <nome>"
    int seek = musicPlay(player, url.c_str(),
                         []() { return gobboTakeTalkRequest(); },       // click = stop
                         []() { return (int)gobboTakeMusicSeek(); });   // premuto+giro = cambia
    if (seek == 0) break;                          // stop / fine stream
    int n = musicStationCount();
    if (n <= 0) break;                             // lista vuota: esci
    if (idx < 0) idx = (seek > 0) ? 0 : n - 1;     // fuori lista: entra dagli estremi
    else { idx = (idx + seek) % n; if (idx < 0) idx += n; }   // ciclico avanti/indietro
    if (!musicStationGet(idx, url, nome)) break;
  }

  ampEnable(false);
  for (int i = 0; i < 10; i++) { micFlush(); delay(40); }
  wakeReset();
  gobboTakeTalkRequest();        // scarta un eventuale click/talk accumulato
  gobboTakeMusicSeek();          // scarta seek residui (niente salto alla prossima musica)
  gobboClearStopRequest();
  g_audioEndMs = millis();       // finestra di raffreddamento (loop)
  setState(ST_IDLE);
}

// --- Una interazione completa (ascolto -> pensa -> parla) -------------------
static void runInteraction() {
  // 1) ASCOLTO
  gobboClearStopRequest();   // ignora click "vecchi": si ferma solo col prossimo
  setState(ST_LISTENING);    // ora un click dell'encoder = stop registrazione
  if (vsOk) ampEnable(true); // accendi l'ampli: bip e voce passano, poi si muta
  if (vsOk) soundStart(player);

  uint32_t t0 = millis();
  size_t   n  = micRecord(REC_MAX_MS, recKeepGoing, uiSetLevel, gSettings.recSilenceMs);
  if (vsOk) soundStop(player);

  size_t wavLen = 0;
  const uint8_t *wav = micWav(&wavLen);
  float secs = (float)n / (float)micSampleRate();
  Serial.printf("   campioni=%u  durata=%.2fs (%lums)  picco=%d/32767  WAV=%u byte\n",
                (unsigned)n, secs, (unsigned long)(millis() - t0), micLastPeak(),
                (unsigned)wavLen);

  // troppo corto: probabilmente premuto per sbaglio
  if (n < (size_t)(micSampleRate() / 4)) {
    if (vsOk) ampEnable(false);   // muta l'ampli prima di tornare a riposo
    setState(ST_IDLE);
    return;
  }
  // Nessuna voce VERA rilevata (solo silenzio/rumore): probabile falso avvio
  // (wake fantasma / click). NON mandare a Whisper (allucinerebbe "Grazie" e
  // farebbe ripartire una chat). Torna a riposo in silenzio.
  if (!micHeardVoice()) {
    Serial.println(">> nessuna voce rilevata: ignoro (niente Whisper)");
    if (vsOk) ampEnable(false);
    setState(ST_IDLE);
    return;
  }
  if (!wifiOk()) { fail("No WiFi"); return; }

  // 2) PENSO - trascrizione
  setState(ST_THINKING);
  String testo = sttTranscribe(wav, wavLen, "it");
  if (testo.isEmpty()) { fail("Non ho capito"); return; }
  // Filtro anti-allucinazione di Whisper (il "Grazie" fantasma sul silenzio):
  // scarta in silenzio, senza rispondere ne' far ripartire nulla.
  if (isAllucinazione(testo)) {
    Serial.printf(">> scartata allucinazione STT: \"%s\"\n", testo.c_str());
    if (vsOk) ampEnable(false);
    setState(ST_IDLE);
    return;
  }
  Serial.printf(">> TESTO: \"%s\"\n", testo.c_str());
  gobboPrintUser(testo);   // mostra "Tu: ..." nella chat

  // 2-bis) RISPOSTA PERSONALIZZATA: se la domanda contiene il trigger configurato
  // (gSettings.replyTrigger) uso il testo fisso (replyText) e SALTO musica + Claude.
  String risposta = customReplyMatch(testo);
  bool scripted = risposta.length() > 0;

  if (!scripted) {
    // MUSICA (match LOCALE dalla lista del pannello) -> suona subito, veloce,
    // senza disturbare Claude. Lo stop (click/pannello) e il ritorno pulito a
    // riposo li gestisce playStation().
    {
      String tLowerMus = testo; tLowerMus.toLowerCase();
      const MusicStation *st = musicMatch(tLowerMus);
      if (st && vsOk) { playStation(st); return; }
    }

    // 3) PENSO - cervello. Gli do il tool musica (solo se il VS1053 c'e'): per una
    // richiesta di ASCOLTO non capita dal match locale, Claude sceglie una radio dal
    // catalogo (musicGenre) invece di rispondere a voce -> non "cade" in chat.
    String musicGenre;
    risposta = llmAsk(testo, vsOk ? &musicGenre : nullptr);

    // Claude ha deciso di mettere musica?
    if (vsOk && musicGenre.length()) {
      const MusicStation *cs = musicFromGenre(musicGenre);
      if (cs) { playStation(cs); return; }
      // catalogo senza quel genere: lo dice a voce invece di tacere
      Serial.printf(">> musica: genere \"%s\" non in catalogo\n", musicGenre.c_str());
      risposta = String("Non ho una stazione per ") + musicGenre + ", mi dispiace.";
    }
  }

  if (risposta.isEmpty()) { fail("Errore cervello"); return; }

  Serial.printf(">> ALEXO: \"%s\"\n", risposta.c_str());
  gobboPrint(risposta);   // "Alexo: ..." nella chat (scorre con la voce)

  // 4) PARLO
  if (vsOk) {
    setState(ST_SPEAKING);
    // Se LA TUA frase inizia con la parola-trigger -> voce alternativa.
    String t = testo; t.trim(); t.toLowerCase();
    bool vocaltra = matchAnyTerm(t, gSettings.voiceTrigger, false);  // startsWith uno dei termini
    Serial.printf("[tts] voce: %s\n", vocaltra ? "alternativa" : "default");
    ttsSpeak(player, risposta, vocaltra ? gSettings.voiceIdAlt : String(""));
    delay(50); ampEnable(false);   // lascia sfumare la coda di silenzio, poi muta
    // La coda della VOCE rientra nel mic: raffreddamento come per la musica, cosi'
    // non parte una chat fantasma subito dopo la risposta.
    g_audioEndMs = millis();
  } else {
    Serial.println(">> VS1053 non collegato: salto la voce");
  }
  setState(ST_IDLE);
}
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
void loop() {
  static uint32_t lastInteraction = 0;
  static bool     convActive = false;

  if (wifiOk()) { ArduinoOTA.handle();   // ascolta richieste di aggiornamento OTA
                  netlogHandle();        // mantiene il client Telnet (log via rete)
                  webuiHandle(); }       // serve il pannello impostazioni web

  // Applica eventuali cambi di volume chiesti dall'encoder (premuto + giro).
  // Qui siamo a riposo; durante il parlato ci pensa ttsSpeak (stesso core/bus).
  if (vsOk) volumeApplyPending(player);

  // DOPPIO click dell'encoder = accende/spegne il ring reattivo al suono (toggle
  // runtime). Lo stato vive in gSettings.idleReactive (default = config.h), cosi'
  // e' condiviso col pannello web e salvato in NVS.
  if (encoderDoublePressed()) {
    gSettings.idleReactive = !gSettings.idleReactive;
    settingsSave();
    Serial.printf("[ring] reattivo al suono: %s\n", gSettings.idleReactive ? "ON" : "OFF");
    netlogPrintln(gSettings.idleReactive ? "[ring] reattivo ON" : "[ring] reattivo OFF");
    for (int b = 0; b < 2; b++) { uiSetLevel(150); delay(80); uiSetLevel(0); delay(80); }  // blink di conferma
    if (micOk) micFlush();   // scarta l'audio letto durante il blink (no falso wake)
  }

  // Click dell'encoder a riposo = avvia la chat (toggle: un altro click ferma
  // la registrazione, gestito dentro runInteraction via recKeepGoing).
  // (il && consuma comunque il talk-request; se siamo nel raffreddamento post
  // musica lo scartiamo per non riavviare una chat a vuoto)
  if (gobboTakeTalkRequest() && (millis() - g_audioEndMs) > AUDIO_COOLDOWN_MS) {
    if (!micOk) {
      fail("Mic non pronto");
    } else {
      runInteraction();
      micFlush(); wakeReset();   // scarta l'audio accumulato, niente falso wake
      lastInteraction = millis();
      convActive = true;
    }
  }

  // Avvio chat: il click encoder (sopra) resta SEMPRE attivo in parallelo.
#if WAKE_ENABLE
  // Wake word "Okay Nabu": ascolto CONTINUO del mic (chunk ~20ms). Al
  // riconoscimento avvia la chat come un click encoder. Lo STESSO chunk pilota
  // anche il livello del ring: niente doppia lettura I2S (che ruberebbe meta'
  // dell'audio al modello streaming).
  if (micOk && wakeReady()) {
    static int16_t wbuf[320];
    size_t got = micReadChunk(wbuf, 320);
    if (got) {
      if (wakeFeed(wbuf, got) && (millis() - g_audioEndMs) > AUDIO_COOLDOWN_MS) {
        Serial.println("[wake] *** WAKE WORD! avvio chat ***");
        netlogPrintln("[wake] *** WAKE WORD! avvio chat ***");
        runInteraction();
        micFlush(); wakeReset();   // scarta l'audio della risposta, niente auto-wake
        lastInteraction = millis();
        convActive = true;
      }
  #if IDLE_REACTIVE
      // Livello del ring dallo STESSO chunk (algoritmo buono: passa-alto +
      // auto-floor + envelope). Spento se il toggle (doppio click) e' OFF.
      uiSetLevel(gSettings.idleReactive ? micLevelFromChunk(wbuf, got) : 0);
  #endif
    }
  }
#elif IDLE_REACTIVE
  // Idle reattivo (senza wake): il ring "balla" col suono. micPeekLevel legge
  // l'I2S col passa-alto; va aggiornato OGNI giro o g_level resta "congelato".
  if (micOk) uiSetLevel(gSettings.idleReactive ? micPeekLevel() : 0);
#endif

  // Dopo 2 minuti di inattivita' azzera la memoria: nuova conversazione
  if (convActive && (millis() - lastInteraction) > 120000) {
    llmReset();
    convActive = false;
    Serial.println("[mem] conversazione azzerata (inattivita')");
  }

  delay(8);
}

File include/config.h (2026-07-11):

#pragma once
// ============================================================================
//  ALEXO - Configurazione hardware (ESP32-S3 N16R8 DevKitC-1)
//  Modifica qui i pin se hai cablato diversamente. Tutto il resto del codice
//  legge da questo file, quindi non serve toccare altro.
// ============================================================================
//
//  NOTE IMPORTANTI sui pin dell'ESP32-S3 N16R8:
//   - La PSRAM octal usa internamente i GPIO 33..37: NON usarli.
//   - GPIO 19/20 sono USB: lasciarli liberi.
//   - L'ADC1 (per il microfono analogico) e' sui GPIO 1..10.
//   - GPIO 0 / 45 / 46 / 3 sono strapping pin: evitarli per le periferiche.
//
// ----------------------------------------------------------------------------

// --- Display TFT ST7735 1.8" 128x160 (SPI) ----------------------------------
//  Display TEMPORANEO (in attesa del 5"). Sta su un bus SPI DEDICATO (HSPI),
//  separato da quello del VS1053 (FSPI): cosi' lo scroll della chat sul core 0
//  non litiga col feed audio sul core 1 (niente singhiozzi).
//  Tutti GPIO liberi (non strapping, non USB, non ADC2, non PSRAM).
//  Cablaggio modulo ST7735: VCC->3V3  GND->GND  LED/BL->3V3  e i pin sotto.
#define TFT_SCLK_PIN     2      // SCK / SCL
#define TFT_MOSI_PIN     1      // SDA / MOSI (DIN)
#define TFT_CS_PIN       42     // CS
#define TFT_DC_PIN       41     // DC / A0 / RS
#define TFT_RST_PIN      40     // RES / RST
#define TFT_WIDTH        128
#define TFT_HEIGHT       160
//  Variante del "tab" del modulo: se i colori sono invertiti o c'e' un bordo,
//  prova INITR_GREENTAB o INITR_REDTAB. Il classico 1.8" rosso e' BLACKTAB.
#define TFT_INITR        INITR_BLACKTAB
//  Clock SPI del TFT. Il lampeggio del ring durante lo
//  scroll era EMI dei fronti SPI accoppiati sul filo DIN del WS2812: a 2MHz
//  spariva ma lo scroll andava "a onde" (blit a schermo intero ~164ms = raster
//  lento e visibile). FIX HW: DIN allontanato dai fili SCLK/MOSI (+ event. 330ohm
//  serie sul DIN) -> si puo' tenere il clock alto. 24MHz = blit ~14ms, scroll
//  liscio. Se il TUO modulo mostra garbage a 24MHz, scendi a 16/20 MHz.
#define TFT_SPI_HZ       24000000

//  Retroilluminazione (LED/BL) pilotata da GPIO, NON piu' fissa a 3V3: cosi'
//  possiamo spegnerla a riposo per risparmiare. Il pin assorbe pochissimo
//  (~2 mA misurati col multimetro) -> si pilota DIRETTAMENTE dal GPIO, senza
//  transistor ne' resistenza esterna. HIGH = acceso, LOW = spento.
//  CABLAGGIO: il pin LED/BL del modulo va a GPIO14 (prima andava a 3V3). GPIO14
//  era libero (ex push-to-talk). Il catodo del LED e' gia' a GND dentro il modulo.
#define TFT_BL_PIN       14
//  Dopo questi ms SENZA interventi (nessun click/giro encoder/nuovo messaggio,
//  e Alexo a riposo) il display si spegne; si riaccende al primo intervento.
//  Metti 0 per tenerlo sempre acceso.
#define DISPLAY_SLEEP_MS 120000   // 2 minuti
//  Splash animato all'accensione (HUD futuristico su TFT + ring "carica"). 0 = off.
#define SPLASH_BOOT      1

// --- Ring NeoPixel 12 LED WS2812 --------------------------------------------
#define LED_RING_PIN     48     // data in del ring
#define LED_RING_COUNT   12
#define LED_BRIGHTNESS   40     // 0-255, tienilo basso per non scaldare/assorbire troppo
//  Idle reattivo al suono: 1 = ring "balla" col microfono a riposo (psichedelico),
//  0 = ring SPENTO a riposo (luci solo negli stati attivi). Riacceso
//  dopo il fix del rumore mic (passa-alto in mic.cpp): ora il fondo a riposo e'
//  basso e il ring non lampeggia piu' a vuoto.
#define IDLE_REACTIVE    1

// --- Bottone push-to-talk (RIMOSSO) -----------------------------------------
//  Storico: c'era un bottone dedicato su GPIO14. Ora l'UNICO comando e' il
//  pulsante dell'encoder (vedi sotto): click = avvia/ferma la chat, premuto+giro
//  = volume, giro = scroll. GPIO14 e' ora usato dal backlight del display
//  (TFT_BL_PIN sopra). Define rimossi (non piu' usati da nessuna parte).

// --- MICROFONO --------------------------------------------------------------
//  Selezione del microfono. L'API software e' identica per entrambi, quindi
//  per cambiare basta questa riga (e ricablare): NON si tocca altro codice.
//    0 = MAX4466 analogico (attuale, su ADC1)
//    1 = mic I2S digitale (ICS-43434 / INMP441) -> metti 1, ricompila, flasha
#define MIC_USE_I2S      1

#define MIC_SAMPLE_RATE  16000  // Hz, quello che vuole Whisper (per entrambi)

//  MAX4466 (analogico, usato se MIC_USE_I2S = 0)
#define MIC_ADC_PIN      4      // GPIO4 = ADC1_CH3 (uscita analogica del mic)
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

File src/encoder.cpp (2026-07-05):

// ============================================================================
//  ALEXO - Encoder rotativo (vedi encoder.h).
//  Backend: libreria Versatile_RotaryEncoder (ruiseixasm) - decodifica robusta
//  a polling + gestione completa degli eventi del pulsante. L'API pubblica resta
//  identica a prima (encoderTake / encoderButtonHeld / ...) cosi' gobbo.cpp e
//  main.cpp non cambiano.
//
//  La libreria e' a POLLING: va interrogata spesso con ReadEncoder(). Per non
//  perdere passi quando il loop principale (core 1) e' bloccato su rete, la
//  interroghiamo da un TASK dedicato ad alta frequenza (~1ms). I callback
//  girano dentro quel task e accumulano in variabili volatili che l'API legge.
// ============================================================================
#include "encoder.h"
#include "config.h"
#include <Versatile_RotaryEncoder.h>

static Versatile_RotaryEncoder *enc = nullptr;

static volatile int32_t encDelta   = 0;   // detenti accumulati (giro, +1/-1 per scatto)
static volatile bool    btnHeld    = false; // true mentre il pulsante e' premuto
static volatile bool    clickEvent = false; // CLICK SINGOLO confermato (differito)
static volatile bool    dblEvent   = false; // DOPPIO click

// Disambiguazione singolo vs doppio: al rilascio di una pressione semplice (senza
// giro) NON emetto subito il singolo, ma avvio un timer; se entro DOUBLE_WINDOW_MS
// arriva un secondo click la libreria chiama onDoublePress (-> annullo il pending
// e emetto un doppio), altrimenti scaduta la finestra confermo il singolo.
#define DOUBLE_WINDOW_MS 350
static volatile bool     rotated       = false;   // ha girato mentre premuto? -> non e' un click
static volatile bool     inDouble      = false;   // questa pressione fa parte di un doppio
static volatile bool     pendingSingle = false;
static volatile uint32_t pressDownAt   = 0;       // istante dell'ULTIMA pressione (riferimento finestra)

// --- Callback della libreria (girano nel task di polling) -------------------
static void onRotate(int8_t r)      { encDelta += r; }                 // giro libero -> scroll
static void onPressRotate(int8_t r) { encDelta += r; rotated = true; } // premuto + giro -> volume
static void onHeldRotate(int8_t r)  { encDelta += r; rotated = true; }

// La finestra del doppio si misura dalla PRESSIONE (come fa la libreria). Al
// rilascio "pulito" (no giro, non e' il 2o di un doppio) armo un singolo PENDENTE
// che il task confermera' solo se la finestra scade senza un 2o click. Se invece
// arriva il doppio (onDoublePress), annullo il pendente e marco inDouble cosi' il
// rilascio successivo NON ri-arma un singolo (era il bug: scattava la chat).
static void onPress()               { btnHeld = true; rotated = false; inDouble = false; pressDownAt = millis(); }
static void onPressRelease()        { btnHeld = false; if (!rotated && !inDouble) pendingSingle = true; rotated = false; inDouble = false; }
static void onLongPressRelease()    { btnHeld = false; if (!rotated && !inDouble) pendingSingle = true; rotated = false; inDouble = false; }
static void onPressRotateRelease()  { btnHeld = false; rotated = false; }               // ha girato -> no click
static void onHeldRotateRelease()   { btnHeld = false; rotated = false; }
static void onDoublePress()         { btnHeld = true; pendingSingle = false; dblEvent = true; inDouble = true; }

// --- Task di polling (interroga la libreria ogni ~1ms) ----------------------
static void encoderTask(void *) {
  for (;;) {
    enc->ReadEncoder();
    // conferma il click singolo se la finestra del doppio e' passata (dalla pressione)
    if (pendingSingle && (millis() - pressDownAt) >= DOUBLE_WINDOW_MS) {
      pendingSingle = false;
      clickEvent = true;
    }
    vTaskDelay(1);   // 1 tick = 1ms (FreeRTOS @1kHz); ReadEncoder si auto-limita a 1ms
  }
}

void encoderBegin() {
  // clk = A (CLK), dt = B (DT), sw = pulsante. Pull-up interni li mette la libreria.
  enc = new Versatile_RotaryEncoder(ENC_A_PIN, ENC_B_PIN, ENC_SW_PIN);

  enc->setHandleRotate(onRotate);
  enc->setHandlePressRotate(onPressRotate);
  enc->setHandleHeldRotate(onHeldRotate);
  enc->setHandlePress(onPress);
  enc->setHandleDoublePress(onDoublePress);
  enc->setHandlePressRelease(onPressRelease);
  enc->setHandleLongPressRelease(onLongPressRelease);
  enc->setHandlePressRotateRelease(onPressRotateRelease);
  enc->setHandleHeldRotateRelease(onHeldRotateRelease);
  enc->setDoublePressDuration(DOUBLE_WINDOW_MS);   // finestra del doppio click

  encDelta = 0; btnHeld = false; clickEvent = false; dblEvent = false; pendingSingle = false; inDouble = false;

  // Task leggero sul core 0 (come ui/gobbo); il loop di rete sta sul core 1.
  xTaskCreatePinnedToCore(encoderTask, "enc", 2048, nullptr, 2, nullptr, 0);
}

int32_t encoderTake() {
  int32_t d = encDelta;
  encDelta -= d;        // sottraggo invece di azzerare: non perdo scatti arrivati nel frattempo
  return d;
}

bool encoderButtonPressed() {
  if (clickEvent) { clickEvent = false; return true; }
  return false;
}

bool encoderDoublePressed() {
  if (dblEvent) { dblEvent = false; return true; }
  return false;
}

bool encoderButtonHeld() {
  return btnHeld;
}

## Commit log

2026-07-05 Alexo — assistente vocale fai-da-te su ESP32-S3
    [baseTpu-Corpo.stl, basetta ampli.stl, contenitore4-basetta vs1053-1.stl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]
2026-07-11 Sistemazioni varie agli asset principali e inserimento ringraziamento all'AI Claude
    [portaled3.3mf]
2026-07-11 File 3D per MakerWorld: rinomina parti, progetto Alexo.3mf e foto cover
    - Rinominati gli STL con nomi puliti (contenitore, basetta vs1053, coperchio
    portaled, base e guarnizione in TPU)
    - Aggiunto Alexo.3mf (preset di sistema Bambu A1 mini, Generic PETG/TPU)
    - Aggiunta cover.jpeg (foto reale del pezzo stampato) per il listing
    [Alexo.3mf, base.stl, basetta vs1053.stl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]
2026-07-11 Rimuove i collage promo orfani dal repo (spostati in locale)
    image.png, social_alexo.png e social-preview-github.png erano materiale
    grafico non referenziato da alcun documento: tolti dal repo pubblico.
    L'immagine hero resta IMMAGINI/alexo.png (usata dal README).
2026-07-11 README: aggiunge il link al case 3D su MakerWorld (CC BY 4.0)
    Cross-link tra il repo e il modello stampabile pubblicato su MakerWorld.
2026-07-11 Sistemazione piatto 2 del file 3mf
    [Alexo.3mf]
